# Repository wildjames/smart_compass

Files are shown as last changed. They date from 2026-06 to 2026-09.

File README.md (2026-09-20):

# Smart Compass

The product is going to be something similar to the compass in the Pirates of the Caribbean.

It has a ring of LEDs that indicate the direction you need to walk in to get to the place you want to be, which can be other devices in a tracking group, waypoints on a navigation route (e.g. hiking), Atlas Obscura sites for the city you're in, or some location you pinned (e.g. where you parked your car, or something like that).
Locations will be either pins dropped by the compass itself, or loaded to the device using a companion app on a phone - communicating with that means the device needs BLE. The nRF52840 module gives that.

The compass has a GNSS module for getting its own location, and a 9-axis IMU for the compass orientation.
It has a LoRa radio for kilometer-range mesh networking, allowing it to maintain an off-grid communication layer in cases where the cell network is either unavailable (e.g. rural locations, mountains), or overloaded (e.g. music festivals and other large events) - or if you just don't want to be carrying a phone (e.g. a kid being set loose in a shopping centre).

For typical single-device operation, however, the compass will rely on a companion phone app. Using the app, the user can navigate to desired location without referring to their phone. These can be user-defined, like setting the navigation destination on Maps, or get a list of Locations of Interest (LoI) from something like Atlas Obscura. I could also do a "hot/cold" thing with phone RSSI signal strength to get a kind of phone finder feature, but that may not be very useful.

## Design requirements

The device has a few core requirements:

- It must operate with no companion phone or PC. It's fine to have a phone for initial setup, or for additional features, but peer-to-peer operation must be entirely on-device.
- Tracking must be done by the device. The GNSS network must be used for this.
- The device must be secure - there must be no way for non-paired devices to be able to discern the location of a device, even if they are part of the same mesh network.
- Communication between devices must be long-range. Kilometer ranges between peers is a requirement, and longer ranges with a mesh network is also necessary.
- The battery must last for at least a day, but 3 day battery life is the target. Deep sleep, low power, and high polling modes should be used to assist this.
- The device must be handheld. No external antenna is ideal, but the option to add one may be worthwhile.
- The device must have flash storage
- The device needs an on-board way to communicate the direction and distance of paired devices.
  - The device must have a ring of addressable RGB LEDs for peer indication.
  - The device must have a haptic engine for feedback
  - The device may have a speaker for feedback.

I'm writing down user flows as I think of them in the [User Flow Library](UserFlowLibrary.md) page.

-----

## Archived KiCAD packages

- 0.1: First edition.
- 0.2: Submitted to reddit for hope of review. First hierarchical schematic.
- 0.3: Reviewed connections, fixed a few bugs with USB and SPI.
- 0.4: Rerouted the board to place the e-ink connector correctly, and the MCU more centrally. Also made the antenna placement more seriously, with proper clearance zone and via stitching.

-----

## Thoughts

The component cost per device is up to ~£50. The boards are about £5 per board for the first run (some heavy discounts, I shouldn't squander that). Assembled, the first shipment of 5 boards would cost $115 plus ~$60 in components per board makes that up to $400. That's a hefty chunk of cash. I could try getting just two assembled for this initial run, which brings it down to like, $200, but that's still pricey.

## TODO list

- Breaking the LED ring and display out to daughter boards is in progress. The two new schematics exist at [boards/led_ring/](boards/led_ring/) and [boards/display/](boards/display/); see [boards/README.md](boards/README.md) for the interconnect pinouts and what still has to be stripped out of the main board.
  - Similarly, it may be worth breaking the LoRa and GNSS out to a daughter board, which may make the antenna placement easier. Less compelling though, and probably not worth the extra thickness.
- I can apparently use a pi pico 2 as an SWD programmer, to flash the bootloader, and from there I can just upload via the native USB. I need to prove this out though.
- I will do the programming in Rust, using the Embassy ecosystem. This will give me the memory safety and speed of rust (nice when there is no easy way to see crashes on the device), but also the fearless concurrency will be a massive boon with all the ICs that need to be interfaced with.

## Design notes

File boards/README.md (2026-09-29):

# Board set

The Smart Compass is built as three PCBs. KiCad has no multi-board project, so
each one is its own project directory here, and the parts they share live in
`../libs/`.

| Directory | Project | What it is |
| --- | --- | --- |
| `main/` | `SmartCompass` | The engine board: MCU, GNSS, LoRa, IMU, flash, power tree, haptics, buttons, USB |
| `led_ring/` | `LedRing` | The 16-LED addressable RGB ring |
| `display/` | `Display` | The e-ink panel connector and its charge-pump support |

The ring and display were split off so the housing can be assembled and
modified without the main board's position dictating where they sit.

Parts that are not on any board - the haptic actuator, the panel, the cell, the
case switches and buttons, the antennas, and the cables and housings joining
them - are listed in [EXTRA_PARTS_BOM.md](EXTRA_PARTS_BOM.md), because they never
appear in a BOM exported from a schematic. Outstanding sourcing work and open
risks are in [COMPONENT_SOURCING.md](COMPONENT_SOURCING.md).

The main board's power tree can be simulated in KiCad's built-in SPICE
simulator; [main/sim/README.md](main/sim/README.md) explains the setup, what is
modelled and excluded, and the results so far. The part models are in
`../libs/spice/`.

## Libraries

`../libs/smart_compass.kicad_sym` and `../libs/smart_compass.pretty` hold the
parts the boards share. They were extracted from the main board, where they had
only ever existed embedded inside the `.kicad_sch` and `.kicad_pcb` files - they
were never in any library table, so a new project could not place them.

Footprints live alongside in `../libs/smart_compass.pretty/`, and 3D models in
`../libs/smart_compass.3dshapes/`.

3D models are referenced from inside the footprint with a
`${KIPRJMOD}/../../libs/smart_compass.3dshapes/...` path
The main board still resolves its other custom parts from its embedded copies,
which is why its ERC reports a long list of "configuration does not include
the symbol library" warnings. Those predate the split. Extracting the rest
into `libs/` would clear them.

Each daughter board has a project-scope `sym-lib-table` and `fp-lib-table`
pointing at `${KIPRJMOD}/../../libs/`, so the paths survive the repo being
cloned somewhere else.

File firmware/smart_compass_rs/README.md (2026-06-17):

# Smart compass firmware

There are a lot of things that need to be interfaced with. I'm going to go with Rust here, for the concurrency benefits and the seemingly mature ecosystem, though I'll have to evaluate that as I go...

## List of core dependencies

| Crate | Responsibility | Docs |
|---|---|---|
| `cortex-m` | Low-level access to Cortex-M peripherals (NVIC, SCB), critical section implementation for single-core nRF52840 | [docs.rs/cortex-m](https://docs.rs/cortex-m/0.7.7/cortex_m/) |
| `cortex-m-rt` | Startup runtime - defines the reset vector, memory layout, and `#[entry]` macro | [docs.rs/cortex-m-rt](https://docs.rs/cortex-m-rt/0.7.5/cortex_m_rt/) |
| `defmt` | Lightweight, deferred formatting logging framework for embedded (sends minimal data over RTT) | [docs.rs/defmt](https://docs.rs/defmt/1.1.0/defmt/) |
| `defmt-rtt` | Transport layer that streams `defmt` log frames over RTT (via SWD probe) | [docs.rs/defmt-rtt](https://docs.rs/defmt-rtt/1.2.0/defmt_rtt/) |
| `embassy-executor` | Async task executor for Cortex-M - runs Embassy tasks cooperatively | [docs.rs/embassy-executor](https://docs.rs/embassy-executor/0.10.0/embassy_executor/) |
| `embassy-nrf` | Hardware Abstraction Layer for nRF52840 - provides async drivers for GPIO, I2C, SPI, UART, PWM, etc. | [docs.rs/embassy-nrf](https://docs.rs/embassy-nrf/0.10.0/embassy_nrf/) |
| `embassy-time` | Async timers, delays, and time-keeping backed by the RTC peripheral | [docs.rs/embassy-time](https://docs.rs/embassy-time/0.5.1/embassy_time/) |
| `embedded-hal` | Standard hardware abstraction traits (I2C, SPI, GPIO) for portable device drivers | [docs.rs/embedded-hal](https://docs.rs/embedded-hal/1.0.0/embedded_hal/) |
| `nrf-sdc` | Rust bindings to Nordic's SoftDevice Controller - provides the BLE link layer | [docs.rs/nrf-sdc](https://docs.rs/nrf-sdc/0.3.0/nrf_sdc/) |
| `trouble-host` | BLE host stack (GATT, GAP) that runs on top of `nrf-sdc` - handles connections, services, characteristics | [docs.rs/trouble-host](https://docs.rs/trouble-host/0.6.0/trouble_host/) |

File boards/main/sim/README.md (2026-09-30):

# SPICE simulation of the main board

The main board schematic is set up for KiCad's built-in simulator (ngspice).
It simulates the power tree: USB input, charger, load-sharing power path,
3.3 V regulator, and the LED ring and haptics, which hang off the power path
output.
Everything else on the board appears as the current it draws.

## Running it

1. Open `SmartCompass.kicad_pro` and the schematic, then **Inspect → Simulator**.
2. Run the simulation. If KiCad asks for an analysis, choose a transient with
   a 10 µs step and a 3 s stop time. That is the `.tran` directive on the root
   sheet.
3. Add signals to the plot. The useful ones are `VBUS`, `/Power and USB/VSYS`,
   `+BATT`, `+3.3V` and `Vdrive`.

A run takes about 15 seconds.

The scenario is the block of `.param` directives on the root sheet, next to
the flash. Edit those values to change it: cell voltage (`VBAT`), cable
(`RCABLE`, `LCABLE`, `VUSB`), and the time of each event.

| Time | Event |
| ---- | ----- |
| 0 | On battery, idle: MCU running, GNSS acquiring, LoRa receiving, IMU on |
| 0.10 s | LoRa transmits at +22 dBm for 100 ms |
| 0.15 s | LED ring on (0.45 W average, the schematic's "typical") until 2.5 s |
| 0.25 s | Haptic buzz, 100 ms |
| 0.40 s | USB cable plugged in |
| 0.55 s | LoRa transmits again, now on USB |
| 0.70 s | e-ink refresh, 1 s |
| 1.00 s | USB cable pulled out |
| 1.02 s | LoRa transmits while the power path switches back to the cell |

## How it is put together

- **Part models:** [`libs/spice/smart_compass.spice`](../../../libs/spice/smart_compass.spice).
  These cover the charger (MCP73831-2), the 3.3 V LDO (RT9080-33), the
  load-sharing P-FET (DMP2045U), the VBUS Schottky (SS1040-AU), the charge LED
  (LTST-C191KRKT) and the LED-ring ferrite bead (MPZ1608S601A). Each one is
  fitted to its datasheet in `datasheets/`, and the file says which figures.
  The two ICs are behavioural. Their comments list what is modelled and what
  is not.
- **Fixtures:** [`fixtures.spice`](fixtures.spice). These stand in for what
  plugs into the board:
  - a Li-Po cell behind 0.15 Ω on the battery connector;
  - a USB host on the far end of a cable (resistance plus inductance) on the
    USB-C connector;
  - the LED-ring and e-ink boards on their flat-cable connectors.

  The digital and RF modules are modelled as the current they draw.
- **Passives:** resistors and capacitors need no model. KiCad simulates them
  from their values.
- Everything is attached through each symbol's `Sim.*` fields. You can see
  and edit these under Properties → Simulation Model. Load currents are
  subcircuit parameters, so one symbol can be overridden there.

### Load currents

| Load | Draw | Source |
| ---- | ---- | --- |
| nRF52840 module | 6 mA on 3.3 V, 1 µA on its VBUS pin | Estimate. The VBUS figure is kept small so VBUS decays slowly after unplugging, which is the pessimistic case |
| LoRa module | 7.6 mA receiving, 125 mA transmitting | Datasheet |
| GNSS module | 14 mA | Datasheet, acquisition at 3 V |
| IMU | 5 mA | Estimate |
| QSPI flash | 20 µA | Estimate, standby |
| Fuel gauge | 23 µA | Datasheet, active mode |
| Haptic driver + LRA | 60 mA while buzzing | Estimate |
| e-ink board | 8 mA while refreshing | Estimate |
| LED ring board | Power from `Vdrive` behind 32 µF, pulsed at the LEDs' 1 kHz PWM between 0.05 W (dark) and 1.4 W (full white), with the duty set by the average | Derived from the LED datasheet: 0.45 W typical, about 1.4 W with every LED full white |

The LEDs dim by switching each colour fully on or off at 1 kHz, so the ring's
draw is a train of full-power pulses rather than a steady current. The
fixture assumes every LED switches at the same moment. That is the worst
case: in practice each LED has its own oscillator, so they drift in and out
of step.

### Parts excluded from simulation

Every symbol must either have a model or be excluded. ngspice refuses a
circuit in which any node has no DC path to ground. The digital modules are
current sinks between their supply pins, so their signal pins are
unconnected in the simulation. Anything wired only to those pins would
float.

| Excluded | Why |
| --- | --- |
| Both 32.768 kHz crystals and their four 10 pF load capacitors | The oscillators are inside the MCU and IMU, which are only loads here. The capacitors would hang on nodes with no DC path. |
| The two 27 Ω USB data resistors, the 500 Ω NeoPixel data resistor, the 1 kΩ GNSS UART resistor | Each connects two pins that have no model, so both ends float. Signal integrity is not what this simulation looks at. |
| The GNSS antenna, its u.FL connector, the antenna ESD diode, the 0 Ω antenna link and the not-fitted matching parts | RF parts with no meaning at these frequencies. A value of "NM" cannot be simulated at all. |
| The IMU's 0.1 µF CAP capacitor and the haptic driver's 1 µF REG capacitor | Each decouples an internal regulator of an IC modelled only as a load, so it would sit on a floating node. |
| The power-switch pads | Excluding them leaves the switch open, which is the device switched on (the LDO enable is pulled up). |
| The SWD header, reset button, button pads, haptic LRA pads and the NeoPixel-return test point | Connect only to signal pins or to parts already modelled elsewhere. Excluding the buttons leaves them released. |

When you add a symbol to the main board, give it a `Sim.*` model or tick
**Exclude from simulation**. Otherwise the simulator stops with a "no
simulation model" or "singular matrix" error.

## Not simulated

- Thermal regulation in the charger.
- The LDO's current limit and over-temperature shutdown.
- The LDO's power supply rejection. Ripple on `VSYS` only reaches the 3.3 V
  rail in the simulation when the LDO is in dropout.
- The MLCCs' loss of capacitance with DC bias.
- PCB trace resistance and inductance.
- Anything on the LED ring or display boards beyond their input capacitance
  and load.

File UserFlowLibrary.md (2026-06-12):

# User Flows

This is a project where the product will have a fair few things to do with it. Enough that, in order to help me be confident I've thought it through, it's worth making a library of what I want to have in the end.

I'm gonna split this into two parts - first, from the users' perspective, and then from the technical perspective.

For IO, the compass will have 3 user buttons, which will generally fill the role of up, down, and select. There is the e-ink screen for low-cadence information, and the LED ring for high-cadence information. There is also a haptic engine for vibrations, which I won't define here and instead just go by feel later on.

## User perspective

As far as the user is concerned, the device has:
- a name
- a list of devices it is tracking

and a few modes:
- Tracking mode (where the LEDs light up to show the intended direction of travel)
  - Devices/phones
  - Navigation waypoints
  - LoI
- Silent mode (where the device stops reporting its location, but can still track other devices)
- Low-frequency polling mode
- high frequency polling mode

### Phone pairing

- I turn on the device
- I open the bluetooth menu on my phone
- I navigate to the "Set up Compass" settings page in the device screen using the user buttons
- I see the device as "SmartCompass XYZ123" in the available devices menu and connect to it
- I open the app on my phone
- The app knows that a new device has been connected and needs pairing
- The app prompts me for a device name
- I enter it and submit
- After a few moments, I see a confirmation page telling me the device is ready to use

### On-device device pairing

- I have a device that is already set up
- I navigate to the "Add friend" page on the device screen on device A
- The other party navigates to the "Add friend" page on the device screen on device B
- I hold the two devices close to each other
- The devices each send a pairing request to each other, and the LEDs indicate a pairing request by flashing the same random colour and pattern
- I press the "select" button to accept, or the "up/down" buttons to reject
  - If either party rejects, then neither device saves the other
  - If the parties take longer than 60s to accept/reject, consider this a rejection
  - If the devices move out of range of each other within the timeout, consider this a rejection
- If/when connected to a companion phone, the device updates it with the current tracked device list

### In-app device pairing

- I have paired a phone to the device
- I open the app and navigate to the "add friend" page
- I search for that friend's username or email
- The other party recieves a request to track
- The other party accepts the request
- I can now track the other party

### Stop location broadcasting (silent mode)

- I have a device set up and paired with a phone
- I turn on the power switch for the device
- The device is broadcasting its location
- I simultaneously press the "up" and "down" user buttons together for 1s
- The device screen indicates that broadcasting has stopped
- The device LED ring indicates that broadcasting has stopped

### Start location broadcasting

- I have a device set up and paired with a phone
- I turn on the power switch for the device
- Location broadcasting is on by default, but the user has turned on silent mode
- The device is not currently broadcasting its location
- I simultaneously press the up and "down" user buttons together for 1s
- The device screen indicates that broadcasting has begun
- The device LED ring indicates that broadcasting has begun

### Start HTR broadcasting

- I have a device set up and paired with a phone
- The device is currently broadcasting a location
- I use the 3 user buttons to navigate the on-screen menu to the location broadcasting page
- I select the "Start HTR sharing" option

### Stop HTR broadcasting

- I have a device set up and paired with a phone
- The device is currently broadcasting a location
- I use the 3 user buttons to navigate the on-screen menu to the location broadcasting page
- I select the "Stop HTR sharing" option

### Set navigation route

- I have a device set up and paired with a phone
- The device is currently connected to the phone
- I open the app and navigate to the "Navigation" page
- I type in a destination to the search box
- The app returns results from Google Maps
- I select a target location
- The app indicates that navigation has started
- The app shows the route
- The device screen indicates that navigation has started, and displays key information about the route
- The device LED ring indicates that navigation has started, then points to the first waypoint along the route
- The screen updates key information on a 60s cadence
- The user is able to cancel navigation by either powering off the device (no resume on reboot), or double-tapping the "select" button
- When the user arrives at the waypoint, the LED ring indicates a waypoint was reached and begins tracking the next waypoint
- When the user arrives at the destination, the LED ring indicates arrival and the screen updates to do the same.

### Track LoI nearby

- I have a device set up and paired with a phone
- The device is currently connected to the phone, which is used to fetch data
- I use the 3 user buttons to navigate to "Track nearby LoI"
- The LED ring indicates the direction of the 3 nearest LoI
- The screen shows the name of the LoI that is currently closest to 0 degrees, and the distance to it
- When the user arrives at an LoI, the device LED ring indicates arrival
- The screen shows the LoI name
- When the user arrives at an LoI, the phone app sends a notification and opens the wikipedia page for it

### Start tracking a specific person

- I have a device set up
- I use the 3 user buttons to navigate to "Track person"
- I see a list of paired people, with untrackable people grayed out
  - "Untrackable" means no location data currently available for that person
  - I may add a "Patchy signal" mode, where the last known location can still be tracked?
- I use the user buttons to navigate to the person to track, and select them
- The LED ring indicates the direction of the person being tracked
- The device screen shows the name of the person being tracked

### Define a tracking group

- I have a device set up and paired with a phone
- The device is currently connected to the phone
- I open the app and navigate to the "Groups" page
- I select "Create new group"
- I enter a group name
- I select members from my list of paired devices/friends
- I confirm the group
- The app shows the new group in my groups list
- The device receives the updated group information

### Start tracking a group of people

- I have a device set up with at least one group defined
- I use the 3 user buttons to navigate to "Track group"
- I use the up/down buttons to scroll through available groups
- I press "select" to choose a group
- The LED ring indicates the direction of each group member with a different colour
- The device screen shows the group name and a list of members with distances

### Stop tracking

- I am currently tracking a person or group
- I long-press the "select" user button
- The LED ring stops indicating directions
- The device screen confirms that tracking has stopped and returns to the main menu

### Power on

TODO

### Power off

TODO

### Low battery indication

TODO

### Firmware update

TODO - Is OTA updating feasible? Perhaps that's the first feature to implement. Can I do it from the app? Directly from a PC?

### Remove a friend

TODO

### Edit a tracking group

TODO

### Delete a tracking group

#### On-device

- I have set up a tracking group previously
- I navigate to the device settings > "Delete tracked thing" menu on the device screen using the 3 user buttons
- I see a menu of "Groups", "Friends", "Locations"
- I select "Groups", and see a list of my tracking group names
- I select the group to delete, and see a "Are you sure?" screen, which contains the group name
- I select "yes" or "no".
- After selection, I return to the list of groups

#### In-app

- I have set up a tracking group previously
- I navigate to the "Manage Tracking Groups" page in the app
- I select the group to delete
- I select the "Delete" button
- I am presented with a confirmation page, and choose an option
- I am returned either to the selected group management page if I do not delete it, or the list of groups page if I did delete the group.

### Tracked person goes offline

TODO

### Tracked person enters silent mode

TODO - should this look the same as the person going offline, or should I communicate the silent mode to the tracker?

## Technical perspective

Each device contains the following information about itself:
- The device name (human-readable)
- The device UUID
- A sigining key pair (pub/priv pair)
- An encryption key pair (pub/priv pair)

Each device tracks the following information about other "partner" devices, for each partner:
- The partner name
- The partner UUID
- The partner public signing key
- The partner public encryption key

Devices have three modes of location broadcasting:
- No broadcasting
- Low time resolution location broadcasting (LTR) (default)
- High time resolution location broadcasting (HTR)

### Phone pairing

This is the initial setup for a user with a new device, or the resetting process for a device that is already set up.

1. The user signals that the device is entering pairing mode
1. The controller clears all previous pairing associations
1. The controller starts the bluetooth radio, if it is not already enabled
1. The controller starts advertising
1. The user pairs their phone to the device
1. The user opens a mobile app, and configures a device name
1. The mobile app sends a message to the device, updating its name
1. The device clears its list of tracked devices, and rotates its cryptographic keys
1. The device sends a message to the app indicating that the setup was successful and informs the app of the device's UUID and public key

### On-device device pairing

This is the process to take two physical devices that are nearby, and set it up so that one tracks the other (device-to-device pairing)

### In-app device pairing

This is the process to use the app to search for another device that is not nearby, and request that partner's information from the remote server (app-to-app pairing)

### Device location broadcasting (LTR)
### Device location broadcasting (HTR)
### Device group tracking
### Device individual tracking

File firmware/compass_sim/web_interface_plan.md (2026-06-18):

# Compass Simulator Web Interface Plan

## Goal

Add a lightweight web UI that allows direct control of mocked ICs while the compass simulator runs indefinitely.

## Architecture

```
┌─────────────┐       ┌──────────────────┐       ┌─────────────┐
│  Browser UI │◄─────►│ Axum HTTP Server │◄─────►│SimController│
│  (HTML/JS)  │  REST │ (localhost:3000) │  Arc  │Arc<Mutex<…>>│
└─────────────┘       └──────────────────┘       └──────┬──────┘
                                                        │
                                                        ▼
                                                 ┌──────────────┐
                                                 │ MockI2cBus   │
                                                 │  ┌─────────┐ │
                                                 │  │FuelGauge│ │
                                                 │  └─────────┘ │
                                                 │  (future ICs)│
                                                 └──────┬───────┘
                                                        │
                                                        ▼
                                                 ┌─────────────┐
                                                 │   Compass   │
                                                 │  (polling)  │
                                                 └─────────────┘
```

The existing `SimController` already uses `Arc<Mutex<...>>` for device state, making it trivially sharable between the compass polling loop and HTTP handlers.

## Dependencies to Add

```toml
axum = "0.8"
serde = { version = "1", features = ["derive"] }
serde_json = "1"
tower-http = { version = "0.6", features = ["cors"] }
```

## REST API Endpoints

| Method | Path | Body | Description |
|---|---|---|---|
| `GET` | `/api/state` | — | Returns full simulator state (voltage, SOC, charge rate, last reading) |
| `POST` | `/api/battery` | `{ "voltage": 3.8, "soc": 62.5 }` | Set battery voltage and SOC |
| `POST` | `/api/charge_rate` | `{ "rate": -2.1 }` | Set charge/discharge rate (%/hr) |
| `POST` | `/api/error` | `{ "kind": "nack" \| "bus_error" }` | Inject a one-shot I2C error |
| `GET` | `/api/fuel_gauge` | — | Latest `Compass::read_fuel_gauge()` result |
| `GET` | `/` | — | Serve the HTML/JS UI |

## Frontend (Single-Page HTML)

A single `index.html` served as an embedded string or from a `static/` directory:

- **Status panel**: Displays current simulated state + last compass reading (auto-refreshes via polling or SSE)
- **Controls**:
  - Voltage slider (2.5V – 4.2V)
  - SOC slider (0% – 100%)
  - Charge rate input (-10 to +10 %/hr)
  - "Inject Error" buttons (NACK, Bus Error)
- **Log**: Scrolling list of compass readings over time

No build tooling — vanilla HTML + JS + fetch API.

## Changes to `main.rs`

Replace the scripted scenario with:

```rust
tokio::select! {
    _ = compass.start() => {},
    _ = web::serve(controller) => {},
}
```

Both tasks run concurrently:
- `compass.start()` polls the mock bus indefinitely
- `web::serve()` runs the axum server on `0.0.0.0:3000`

## File Structure

```
compass_sim/
├── Cargo.toml              (add deps)
├── src/
│   ├── main.rs             (simplified: create sim, start both tasks)
│   ├── lib.rs              (add `pub mod web;`)
│   ├── web/
│   │   ├── mod.rs          (router setup, serve function)
│   │   ├── handlers.rs     (endpoint handler functions)
│   │   └── state.rs        (shared AppState struct)
│   ├── mock/               (unchanged)
│   └── static/
│       └── index.html      (embedded or served from disk)
```

## Implementation Steps

1. Add dependencies to `Cargo.toml`
2. Create `src/web/state.rs` — `AppState` struct wrapping `Arc<SimController>`
3. Create `src/web/handlers.rs` — handler functions for each endpoint
4. Create `src/web/mod.rs` — router construction and `serve()` async fn
5. Create `src/static/index.html` — single-page UI
6. Update `src/lib.rs` to export `pub mod web`
7. Rewrite `src/main.rs` to run indefinitely with both tasks
8. Test: `cargo run`, open `http://localhost:3000`

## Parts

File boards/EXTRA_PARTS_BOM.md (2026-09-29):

# Extra parts BOM

Everything the finished compass needs that is **not** on a board, and so never
appears in a BOM exported from a schematic.

Quantities are per finished unit unless stated. Stock and lead figures were read
from Digi-Key and will drift; re-check before ordering.

## Ready to order

| Part | What it is | Qty | Digi-Key | Notes |
| ---- | --- | --- | --- | ----- |
| Vybronics `VLV101040A` | Haptic actuator, 10 x 10 x 4 mm linear resonant | 1 | `1670-VLV101040A-ND` | [Datasheet](../datasheets/VLV101040A_Vybronics.pdf) |
| 28 AWG stranded hook-up wire, silicone insulated | All five case leads, soldered straight to the board | ~1 m | - | Silicone rather than PVC: the case halves stay tethered once the connectors are gone, so this wire gets flexed every time the unit is opened. Insulation OD should be about 1 mm to suit the pad footprints |
| 32 or 34 AWG UL3302 | The short stub from the actuator pads to the splice | ~100 mm | - | Vybronics only permits this gauge against the actuator's pressure pads |
| Waveshare 1.54inch e-Paper V2 | 200 x 200 panel, SSD1681 driver | 1 | - | The display board is built against this exact module — see [`../datasheets/1.54inch_e-paper_V2_Datasheet.pdf`](../datasheets/1.54inch_e-paper_V2_Datasheet.pdf) |
| Taoglas `FXP890.07.0100C` | LoRa antenna: 863–928 MHz flexible polyimide PCB antenna, 62.2 x 20 mm, 100 mm 1.13 mm coax ending in an I-PEX MHF1 (U.FL) plug | 1 | `931-FXP890.07.0100C-ND` | Plugs straight into the radio module's own onboard IPEX connector. [Datasheet](../datasheets/FXP890.07.0100C_Taoglas.pdf), and see the placement note below |

## Decided, but not yet sourced

| Part | What it is | Qty | Notes |
| ---- | --- | --- | ----- |
| 10-way 0.5 mm FFC cable | Board-to-board, ring link and display link | 2 | Both links use the same connector at both ends, so one cable part serves both. **Length and contact side still to be decided** — see the warning below |
| LiPo cell, 504050 or 505050 | ~1000 mAh, fits behind the PCB | 1 | Almost always ships with a JST PH 2-pin plug already fitted, which mates the board's battery header directly — no crimping needed |
| Power switch | Case-mounted, SMD or through-hole | 1 | Pulls the load switch's enable node down against a 1M pull-up, so the lead carries microamps and current rating is not a constraint here. |
| User Buttons | Case-mounted, SMD or through-holE | 3 | These will be the primary point of contact for the user, so make sure these are good! |

## Notes

**The LoRa antenna sits in the rim.**
Wrapped around the inside of the case, it is bent to a 40 mm radius, which
the polyimide takes easily but which does pull the tuning slightly off the
flat, free-space figures in the datasheet. It may be worth trying to get it
to sit against the face, if possible, to eliminate the bend if this turns out
to be an issue.

Keep it away from the GNSS antenna and lipo as much as possible - nearby metal
interferes with the tuning and will reduce efficiency.

This is an IPEX plug, so we can always move to an external antenna later, if we
need to.

**The FFC cables are not symmetrical.** Both board-to-board links use the same
10-way 0.5 mm connector at both ends, so one cable part number covers both — but
neither pinout is a palindrome, and a cable fitted the wrong way round puts the
LED ring's supply onto ground pins. The ring link also carries the ring's enable
signal on a conductor that used to be a spare supply, which makes getting it
right more consequential than it once was. Both pinouts are in
[`README.md`](README.md), and the conductor order belongs on the assembly
drawing.

**The haptic actuator's contacts are not solder tabs.** It ships with pressure
contacts intended for pogo pins or spring fingers against a PCB. Vybronics
explicitly permits thin flexible flying leads instead — UL3302, AWG 32 or 34 —
which is what the pigtail should use at the actuator end. Do not assume ordinary
hook-up wire will do; it is too stiff for the contact pads and will load the
moving mass.

**The pigtail still needs a splice.** 32/34 AWG is too fine to be the whole run.
It would be fragile against the board pads and is far below the 1 mm insulation
the pad footprint is drawn for. So the thin wire stays a short stub at the
actuator and is spliced to a 28 AWG run, and that run is what solders into the
board. Two things follow,

- **Keep the splice short and put it at the actuator end**, within roughly
  10 mm of the contact pads, so the great majority of the flying lead is the
  stiffer 28 AWG and only a stub of 32/34 AWG is unsupported.
- **Bond the splice down.** It is the weakest joint in the whole assembly — a
  hand-soldered butt joint in a flying lead, on the one lead attached to a
  vibrating mass, inside a device that gets carried in a pocket. Adhesive at
  the splice keeps the vibration out of the joint and stops the moving mass
  being loaded by the heavier wire.

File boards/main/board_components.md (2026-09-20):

# Medallion Board

## External components

All three buttons share one lead, soldered straight into the board. Four plated through-holes with a feed-through strain relief, one per button signal plus a fourth for the ground return they have in common. So the case buttons are built and fitted as one harness rather than three. Use 28 AWG stranded with silicone insulation - the halves stay tethered, so this wire gets flexed every time the unit is opened. I've not settled on buttons yet. There are two options - either side-mounted tactile smd buttons like [these](https://www.amazon.co.uk/ECSiNG-Momentary-5x7-8x3-5mm-Controls-Dashboards/dp/B0GFPX8CMW/ref=sr_1_3?sr=8-3), or through hole button like [this](https://www.amazon.co.uk/10PCS-Momentary-Push-Button-Switch/dp/B0FHVRM49T/ref=sr_1_3?sr=8-3).

There will also be a power switch on the case - it can interface with [this](https://www.amazon.co.uk/sourcingmap%C2%AE-Position-Locking-Switch-7x2x1mm/dp/B01N25FBWD) SMD switch, or possibly the [chunkier cousin](https://www.amazon.co.uk/Miniature-Model-Railway-Switch-2-Position/dp/B00TXNXFZC/) that has through-hole legs.

I should be able to fit a 504050 or 505050 LiPo behind the PCB. That gives approx 1000mAh capacity, e.g. [here](https://www.ebay.co.uk/itm/375695071227) and [here](https://www.ebay.co.uk/itm/195457885965)

For the haptic engine, use the Vybronics `VLV101040A` - a 10 x 10 x 4 mm linear resonant actuator giving 2.75 G at 170 Hz with a 10 ms rise time ([datasheet](../../datasheets/VLV101040A_Vybronics.pdf), and it is on the [extra parts BOM](../EXTRA_PARTS_BOM.md)). It needs to be adhered to the rear of the case to work properly. Note that its contacts are pressure pads meant for pogo pins, not solder tabs - Vybronics permits thin UL3302 AWG 32/34 flying leads instead, which is what the pigtail should be made from.

For the LoRa antenna, I plan on using a PCB antenna, e.g. [here](https://www.amazon.co.uk/915MHz-Antenna-Meshtastic-Development-Boards-Black/dp/B0FLVF19CQ). I think these are flexible PCB antennas, so can bend to fit the contour of the case. This should not affect the performance too much.

## System Block Diagrams

### Power

```mermaid
flowchart LR
    USBC[USB-C X1] -->|VBUS| CHARGER[MCP73831]
    CHARGER --> VBAT[VBAT Rail]
    VBAT --> SUPERCAP[C8 100mF]
    VBAT --> LDO[RT9080-33GJ5]
    VBAT --> VLED[VLED Rail]
    LDO --> VDD[3.3V Rail]

    MCU[nRF52840] <-->|I²C| FUEL[MAX17048 Fuel Gauge]
    FUEL -->|GPIO: LOW_BATT| MCU
    USBC -->|USB D+/D-| MCU
```

### Navigation & Positioning

```mermaid
flowchart LR
    MCU[nRF52840] <-->|UART| GNSS[LC86LICMD GNSS]
    MCU -->|GPIO: GNSS_RESET| GNSS

    MCU <-->|I²C| IMU[BNO086 IMU]
    MCU -->|GPIO: BNO_NINT BNO_NRST| IMU
```

### Communication

```mermaid
flowchart LR
    MCU[nRF52840] <-->|SPI| LORA[LoRa Wio-E5]
    MCU -->|GPIO: LORA_NSS LORA_NRST| LORA
    LORA -->|GPIO: LORA_DIO LORA_BUSY LORA_RF_SW| MCU
```

### Storage

```mermaid
flowchart LR
    MCU[nRF52840] <-->|SPI| FLASH[Flash Memory]
    MCU -->|GPIO: FLASH_CS RST WP| FLASH
```

### Display & Feedback

```mermaid
flowchart LR
    MCU[nRF52840] -->|SPI| J7[J7 FFC]
    MCU -->|GPIO: DISP_CS DC RES BUSY| J7
    J7 --> EINK[Display board]

    MCU -->|1-Wire: NEOPIX| R13[R13 500R]
    R13 --> J6[J6 FFC]
    J6 --> LEDS[LedRing board]
    J6 -->|NEOPIX_RET| TP1[TP1 test pad]

    MCU <-->|I²C| HAPTIC[Haptic Engine]
    MCU -->|GPIO: DRV_EN| HAPTIC
```

### User Input & Debug

```mermaid
flowchart LR
    MCU[nRF52840] -->|GPIO: JST1| BTN1[P3 JST BTN 1]
    MCU -->|GPIO: JST2| BTN2[P5 JST BTN 2]
    MCU -->|GPIO: JST3| BTN3[P4 JST BTN 3]
    MCU --- SW[Reset Button]

    MCU -->|SWD| SWD[SWD Header]
    MCU --> HEADER[GPIO / I²C Breakout]
```

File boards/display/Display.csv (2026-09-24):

Reference | Qty | Value | DNP | Exclude from BOM | Exclude from Board | Footprint | Datasheet | DigiKey_PN | MPN
C1,C3,C4,C5,C7,C8,C10,C11 | 8 | 1uF |  |  |  | Capacitor_SMD:C_0603_1608Metric | https://product.tdk.com/system/files/dam/doc/product/capacitor/ceramic/mlcc/catalog/mlcc_commercial_general_en.pdf | 445-C1608X7R1H105K080ABCT-ND | C1608X7R1H105K080AB
C2 | 1 | 10uF |  |  |  | Capacitor_SMD:C_0805_2012Metric | https://product.tdk.com/system/files/dam/doc/product/capacitor/ceramic/mlcc/catalog/mlcc_automotive_general_en.pdf | 445-6970-1-ND | CGA4J3X5R1A106K125AB
C6,C9 | 2 | 4.7uF |  |  |  | Capacitor_SMD:C_1206_3216Metric | https://mm.digikey.com/Volume0/opasdata/d220001/medias/docus/658/CL31B475KBHNFNE_Spec.pdf | 1276-3179-1-ND | CL31B475KBHNFNE
D1,D2,D3 | 3 | MBR0540 |  |  |  | Diode_SMD:D_SOD-123 | https://www.mccsemi.com/pdf/Products/MBR0520-MBR0580(SOD123).pdf | MBR0540TPMSCT-ND | MBR0540-TP
J1 | 1 | FH12-10S-0.5SH(55) |  |  |  | Connector_FFC-FPC:Hirose_FH12-10S-0.5SH_1x10-1MP_P0.50mm_Horizontal | https://www.hirose.com/product/document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 | HFJ110CT-ND | FH12-10S-0.5SH(55)
J2 | 1 | FH12-24S-0.5SH(55) |  |  |  | smart_compass:HRS_FH12-24S-0.5SH_55_ | https://www.hirose.com/product/document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 | HFJ124CT-ND | FH12-24S-0.5SH(55)
L1 | 1 | 10uH |  |  |  | smart_compass:L_Bourns_SRN3015BTA | https://www.bourns.com/docs/Product-Datasheets/SRN3015BTA.pdf | 118-SRN3015BTA-100MCT-ND | SRN3015BTA-100M
Q1 | 1 | IRLML6346 |  |  |  | Package_TO_SOT_SMD:SOT-23 | https://www.infineon.com/assets/row/public/documents/24/49/infineon-irlml6346-datasheet-en.pdf | IRLML6346TRPBFCT-ND | IRLML6346TRPBF
R1 | 1 | 10K |  |  |  | Resistor_SMD:R_0603_1608Metric | https://yageogroup.com/content/datasheet/asset/file/PYU-RC_GROUP_51_ROHS_L | 311-10.0KHRCT-ND | RC0603FR-0710KL
R2 | 1 | 3R |  |  |  | Resistor_SMD:R_0603_1608Metric | https://yageogroup.com/content/datasheet/asset/file/PYU-RC_GROUP_51_ROHS_L | 13-RC0603FR-073RLCT-ND | RC0603FR-073RL

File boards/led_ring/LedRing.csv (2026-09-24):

Reference | Qty | Value | DNP | Exclude from BOM | Exclude from Board | Footprint | Datasheet | DigiKey_PN | MPN
C1,C3,C4 | 3 | 22uF |  |  |  | Capacitor_SMD:C_0805_2012Metric | https://media.digikey.com/pdf/Data%20Sheets/Samsung%20PDFs/CL21A226KPCLRNC_Spec.pdf | 1276-6786-1-ND | CL21A226KPCLRNC
C2 | 1 | 10uF |  |  |  | Capacitor_SMD:C_0805_2012Metric | https://product.tdk.com/system/files/dam/doc/product/capacitor/ceramic/mlcc/catalog/mlcc_automotive_general_en.pdf | 445-6970-1-ND | CGA4J3X5R1A106K125AB
C5,C6,C7,C8,C9,C10,C11,C12,C13,C14,C15,C16,C17,C18,C19,C20,C21 | 17 | 0.1uF |  |  |  | Capacitor_SMD:C_0402_1005Metric | https://media.digikey.com/pdf/Data%20Sheets/Samsung%20PDFs/CL05B104KO5VPNC_Spec.pdf | 1276-6844-1-ND | CL05B104KO5VPNC
D1,D2,D3,D4,D5,D6,D7,D8,D9,D10,D11,D12,D13,D14,D15,D16 | 16 | IN-PI15TAT5R5G5B |  |  |  | smart_compass:LED_Inolux_IN-PI15TAT5R5G5B_1515 | https://www.inolux-corp.com/details.php?i=286 | 1830-IN-PI15TAT5R5G5BCT-ND | IN-PI15TAT5R5G5B
J1 | 1 | FH12-10S-0.5SH(55) |  |  |  | Connector_FFC-FPC:Hirose_FH12-10S-0.5SH_1x10-1MP_P0.50mm_Horizontal | https://www.hirose.com/product/document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 | HFJ110CT-ND | FH12-10S-0.5SH(55)
L1 | 1 | 2.2uH |  |  |  | Inductor_SMD:L_1008_2520Metric | https://www.murata.com/products/productdetail?partno=DFE252010F-2R2M%3DP2 | 490-13042-1-ND | DFE252010F-2R2M=P2
R1 | 1 | 2.2K |  |  |  | Resistor_SMD:R_0603_1608Metric | https://yageogroup.com/content/datasheet/asset/file/PYU-RC_GROUP_51_ROHS_L | 311-2.20KHRCT-ND | RC0603FR-072K2L
R2 | 1 | 3.9K |  |  |  | Resistor_SMD:R_0603_1608Metric | https://yageogroup.com/content/datasheet/asset/file/PYU-RC_GROUP_51_ROHS_L | 311-3.90KHRCT-ND | RC0603FR-073K9L
R3 | 1 | 732K |  |  |  | Resistor_SMD:R_0603_1608Metric | https://yageogroup.com/content/datasheet/asset/file/PYU-RC_GROUP_51_ROHS_L | 311-732KHRCT-ND | RC0603FR-07732KL
R4 | 1 | 100K |  |  |  | Resistor_SMD:R_0603_1608Metric | https://yageogroup.com/content/datasheet/asset/file/PYU-RC_GROUP_51_ROHS_L | 311-100KHRCT-ND | RC0603FR-07100KL
U1 | 1 | TPS61023 |  |  |  | Package_TO_SOT_SMD:SOT-563 | https://www.ti.com/lit/ds/symlink/tps61023.pdf | 296-TPS61023DRLRCT-ND | TPS61023DRLR
U2 | 1 | 74AHCT1G125 |  |  |  | Package_TO_SOT_SMD:SOT-23-5 | https://www.ti.com/lit/ds/symlink/sn74ahct1g125.pdf | 296-4708-1-ND | SN74AHCT1G125DBVR

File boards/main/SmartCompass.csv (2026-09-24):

Reference | Qty | Value | DNP | Exclude from BOM | Exclude from Board | Footprint | Datasheet | MPN | DigiKey_PN
AE1 | 1 | 1575AT43A0040E |  |  |  | smart_compass:ANT_1575AT_JOT | https://www.johansontechnology.com/part/1575AT43A0040001E/pdf/ | 1575AT43A0040001E | 712-1575AT43A0040001ECT-ND
BATT1 | 1 | JST_PH |  |  |  | smart_compass:JST_S2B-PH-SM4-TB | https://www.jst-mfg.com/product/pdf/eng/ePH.pdf | S2B-PH-SM4-TB | 455-S2B-PH-SM4-TBCT-ND
C1,C2,C8,C9,C10,C12,C19,C22,C24 | 9 | 10uF |  |  |  | Capacitor_SMD:C_0805_2012Metric | https://product.tdk.com/system/files/dam/doc/product/capacitor/ceramic/mlcc/catalog/mlcc_automotive_general_en.pdf | CGA4J3X5R1A106K125AB | 445-6970-1-ND
C3,C4 | 2 | 12pF |  |  |  | Capacitor_SMD:C_0402_1005Metric | https://media.digikey.com/pdf/Data%20Sheets/Samsung%20PDFs/CL05C120JB5NNNC_Spec.pdf | CL05C120JB5NNNC | 1276-1178-1-ND
C5,C20,C21 | 3 | 1uF |  |  |  | Capacitor_SMD:C_0603_1608Metric | https://product.tdk.com/system/files/dam/doc/product/capacitor/ceramic/mlcc/catalog/mlcc_commercial_general_en.pdf | C1608X7R1H105K080AB | 445-C1608X7R1H105K080ABCT-ND
C6,C13,C15,C16,C17,C18,C23 | 7 | 0.1uF |  |  |  | Capacitor_SMD:C_0402_1005Metric | https://media.digikey.com/pdf/Data%20Sheets/Samsung%20PDFs/CL05B104KO5VPNC_Spec.pdf | CL05B104KO5VPNC | 1276-6844-1-ND
C7,C11 | 2 | 4.7uF |  |  |  | Capacitor_SMD:C_1206_3216Metric | https://mm.digikey.com/Volume0/opasdata/d220001/medias/docus/658/CL31B475KBHNFNE_Spec.pdf | CL31B475KBHNFNE | 1276-3179-1-ND
C14 | 1 | 22uF |  |  |  | Capacitor_SMD:C_0805_2012Metric | https://media.digikey.com/pdf/Data%20Sheets/Samsung%20PDFs/CL21A226KPCLRNC_Spec.pdf | CL21A226KPCLRNC | 1276-6786-1-ND
C25,C26 | 2 | NM | DNP |  |  | Capacitor_SMD:C_0402_1005Metric |  | DNP
CHG1 | 1 | RED |  |  |  | LED_SMD:LED_0603_1608Metric | https://optoelectronics.liteon.com/upload/download/DS22-2000-223/LTST-C191KRKT.PDF | LTST-C191KRKT | 160-1447-1-ND
D1 | 1 | MBR0540 |  |  |  | Diode_SMD:D_SOD-123 | https://www.mccsemi.com/pdf/Products/MBR0520-MBR0580(SOD123).pdf | MBR0540-TP | MBR0540TPMSCT-ND
D2 | 1 | TPD1E05U06DPYR |  |  |  | smart_compass:DIO_TPD1E05U06DPYR | https://www.ti.com/general/docs/suppproductinfo.tsp?distId=10 | TPD1E05U06DPYR | 296-39341-1-ND
FB1 | 1 | 600R@100MHz |  |  |  | Inductor_SMD:L_0603_1608Metric | https://product.tdk.com/en/system/files | MPZ1608S601ATA00 | 445-MPZ1608S601ATA00CT-ND
HAPTIC1 | 1 | HAPTIC_PADS |  |  |  | Connector_Wire:SolderWire-0.127sqmm_1x02_P3.7mm_D0.48mm_OD1mm_Relief
IC1 | 1 | Wio-SX1262 |  |  |  | smart_compass:MODULE12P-1.27-11X11.6MM | https://files.seeedstudio.com/products/SenseCAP/Wio_SX1262/Wio-SX1262_Module_Datasheet.pdf | 114993390 | 1597-114993390CT-ND
J3,J4 | 2 | FH12-10S-0.5SH(55) |  |  |  | Connector_FFC-FPC:Hirose_FH12-10S-0.5SH_1x10-1MP_P0.50mm_Horizontal | https://www.hirose.com/product/document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 | FH12-10S-0.5SH(55) | HFJ110CT-ND
J5 | 1 | IPEX |  |  |  | smart_compass:SMT_9.001E.01_TAL | https://cdn.taoglas.com/datasheets/RECE.20369.001E.01.pdf | RECE.20369.001E.01 | 931-1157-1-ND
ONOFF1 | 1 | PWRSW_PADS |  |  |  | Connector_Wire:SolderWire-0.127sqmm_1x02_P3.7mm_D0.48mm_OD1mm_Relief
Q1 | 1 | DMP2045U |  |  |  | Package_TO_SOT_SMD:SOT-23 | https://www.diodes.com/assets/Datasheets/DMP2045U.pdf | DMP2045U-7 | DMP2045U-7DICT-ND
R1,R2,R4,R10 | 4 | 5.1K |  |  |  | Resistor_SMD:R_0603_1608Metric | https://industrial.panasonic.com/cdbs/www-data/pdf/RDA0000/AOA0000C304.pdf | ERJ-3EKF5101V | P5.10KHCT-ND
R3,R5 | 2 | 27R |  |  |  | Resistor_SMD:R_0603_1608Metric | https://yageogroup.com/content/datasheet/asset/file/PYU-RC_GROUP_51_ROHS_L | RC0603FR-0727RL | 311-27.0HRCT-ND
R6,R7 | 2 | 4.7K |  |  |  | Resistor_SMD:R_0603_1608Metric | https://yageogroup.com/content/datasheet/asset/file/PYU-RC_GROUP_51_ROHS_L | RC0603FR-074K7L | 311-4.70KHRCT-ND
R8,R14,R15,R16,R17 | 5 | 10K |  |  |  | Resistor_SMD:R_0603_1608Metric | https://yageogroup.com/content/datasheet/asset/file/PYU-RC_GROUP_51_ROHS_L | RC0603FR-0710KL | 311-10.0KHRCT-ND
R9,R12,R19 | 3 | 100K |  |  |  | Resistor_SMD:R_0603_1608Metric | https://yageogroup.com/content/datasheet/asset/file/PYU-RC_GROUP_51_ROHS_L | RC0603FR-07100KL | 311-100KHRCT-ND
R11 | 1 | 3.9K |  |  |  | Resistor_SMD:R_0603_1608Metric | https://yageogroup.com/content/datasheet/asset/file/PYU-RC_GROUP_51_ROHS_L | RC0603FR-073K9L | 311-3.90KHRCT-ND
R13 | 1 | 500R |  |  |  | Resistor_SMD:R_0603_1608Metric | https://yageogroup.com/content/datasheet/asset/file/PYU-RT_1-TO-0-01_ROHS_L | RT0603BRC07500RL | 13-RT0603BRC07500RLCT-ND
R18 | 1 | NM | DNP |  |  | Resistor_SMD:R_0603_1608Metric |  | DNP
R20,R21 | 2 | 1K |  |  |  | Resistor_SMD:R_0603_1608Metric | https://yageogroup.com/content/datasheet/asset/file/PYU-RC_GROUP_51_ROHS_L | RC0603FR-071KL | 311-1.00KHRCT-ND
R22 | 1 | 0R |  |  |  | Resistor_SMD:R_0603_1608Metric | https://yageogroup.com/content/datasheet/asset/file/PYU-RC_GROUP_51_ROHS_L | RC0603JR-070RL | 311-0.0GRCT-ND
RESET1 | 1 | KMR2 |  |  |  | Button_Switch_SMD:SW_Push_1P1T-SH_NO_CK_KMR2xxG | https://www.littelfuse.com/assetdocs/littelfuse-c-k-tactile-kmr2-series-datasheet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 | KMR221NG LFS | CKN10244CT-ND
U1 | 1 | BMD-340-A-R |  |  |  | smart_compass:RIGADO_BMD-340-A-R | https://content.u-blox.com/sites/default/files/BMD-340_DataSheet_UBX-19033353.pdf | BMD-340-A-R | 672-BMD-340-A-RCT-ND
U2 | 1 | S25FL064LABNFI043 |  |  |  | smart_compass:SON80P400X400X60-9N | https://www.infineon.com/assets/row/public/documents/10/49/infineon-s25fl064l-64-mbit-8-mbyte-3-datasheet-en.pdf | S25FL064LABNFI043 | 448-S25FL064LABNFI043CT-ND
U3 | 1 | RT9080-33GJ5 |  |  |  | smart_compass:SOT94P280X100-5N | https://www.richtek.com/SaveDownload.aspx?specid=RT9080 | RT9080-33GJ5 | 1028-1509-1-ND
U4 | 1 | MCP73831T-2ACI_OT |  |  |  | smart_compass:SOT95P280X145-5N | https://ww1.microchip.com/downloads/aemDocuments/documents/APID/ProductDocuments/DataSheets/MCP73831-Family-Data-Sheet-DS20001984H.pdf | MCP73831T-2ACI/OT | MCP73831T-2ACI/OTCT-ND
U5 | 1 | MAX17048G_T10 |  |  |  | smart_compass:SON50P200X200X80-9N | https://www.analog.com/media/en/technical-documentation/data-sheets/MAX17048-MAX17049.pdf | MAX17048G+T10 | MAX17048G+T10CT-ND
U6 | 1 | BNO086 |  |  |  | smart_compass:IC_BNO086 | https://www.ceva-ip.com/wp-content/uploads/BNO080_085-Datasheet.pdf | BNO086 | 1888-BNO086CT-ND
U7 | 1 | DRV2605LDGSR |  |  |  | smart_compass:SOP50P490X110-10N | https://www.ti.com/lit/ds/symlink/drv2605l.pdf?HQS=dis-dk-null-digikeymode-dsf-pf-null-wwe&ts=1780420623353 | DRV2605LDGSR | 296-40032-1-ND
U8 | 1 | MAX-M10S-00B |  |  |  | smart_compass:XCVR_MAX-M10S-00B | https://content.u-blox.com/sites/default/files/MAX-M10S_DataSheet_UBX-20035208.pdf | MAX-M10S-00B | 672-MAX-M10S-00BCT-ND
X1 | 1 | USB4085-GF-A |  |  |  | smart_compass:GCT_USB4085-GF-A_REVA4 | https://gct.co/files/specs/usb4085-spec.pdf | USB4085-GF-A | 2073-USB4085-GF-ACT-ND
Y1 | 1 | 32.768KHZ |  |  |  | smart_compass:XTAL_ABS07-32.768KHZ-7-T | https://abracon.com/Resonators/ABS07.pdf | ABS07-32.768KHZ-7-T | 535-9543-1-ND

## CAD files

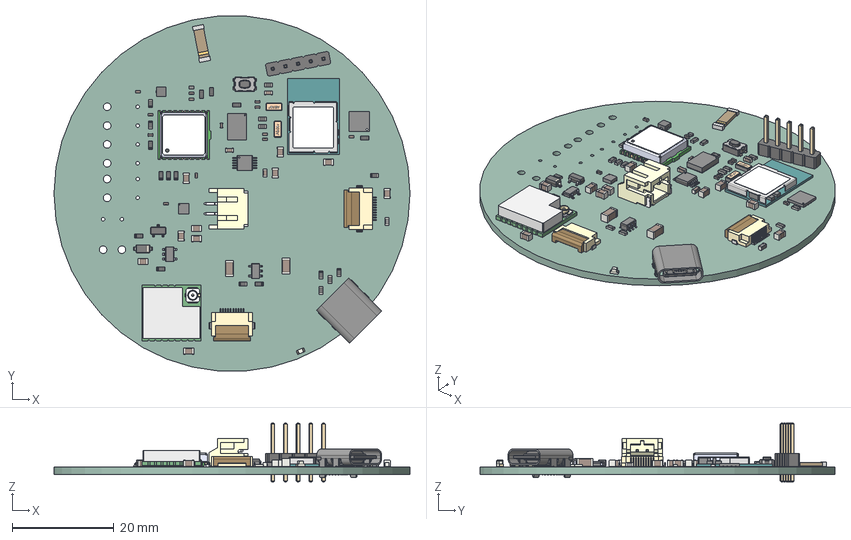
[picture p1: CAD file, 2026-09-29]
boards/main/main.step
70.0 x 69.8 x 11.5 mm
S2B-PH-SM4-TB(LF)(SN)
R_0603_1608Metric x 22
MAX17048G+T10
SOT-23
C_0805_2012Metric x 10
S25FL064LABNFI043
C_0402_1005Metric x 13
C_1206_3216Metric x 2
C_0603_1608Metric x 3
ABS07 x 2
DPY2
L_0603_1608Metric
BNO085
lock x 2
pins x 2
MAX-M10S-00B
BMD-340-A-R
MCP73831T-2ACI_OT
PinHeader_1x05_P254mm_Vertical
User_Library-IPEX
Extruded
SW_Push_1P1T-SH_NO_CK_KMR2xxG
RT9080-xGJ
D_SOD-123
Body001 (Mirror #1) x 5
XY-plane x 12
X-axis x 12
USB_C_Receptacle_GCT_USB4085
LED_0603_1608Metric
SmartCompass_PCB

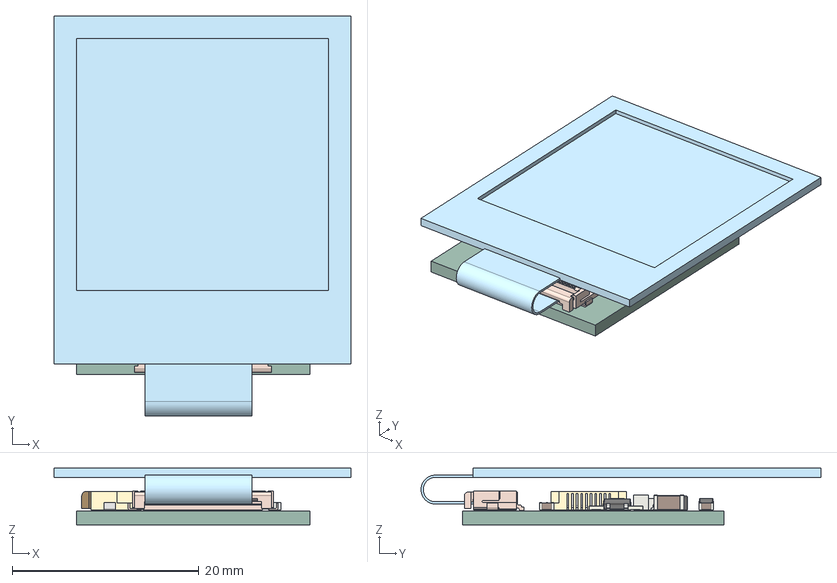
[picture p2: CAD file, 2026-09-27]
boards/display/Display.step
31.8 x 42.9 x 6.09 mm
C_0603_1608Metric x 8
D_SOD-123 x 3
C_0805_2012Metric
FH12-24S-0.5SH_Èª
R_0603_1608Metric x 2
C_1206_3216Metric x 2
L_APV_ANR3015
SOT-23
lock
pins
Display_PCB

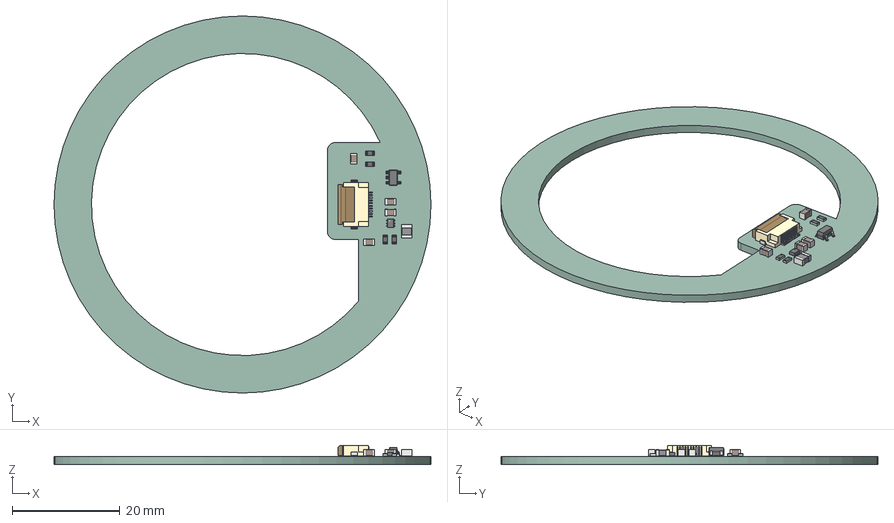
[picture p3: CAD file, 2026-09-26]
boards/led_ring/LedRing.step
70.0 x 70.0 x 3.59 mm
L_1008_2520Metric
R_0603_1608Metric x 4
C_0805_2012Metric x 4
SOT-23-5
lock
pins
SOT_563
LedRing_PCB

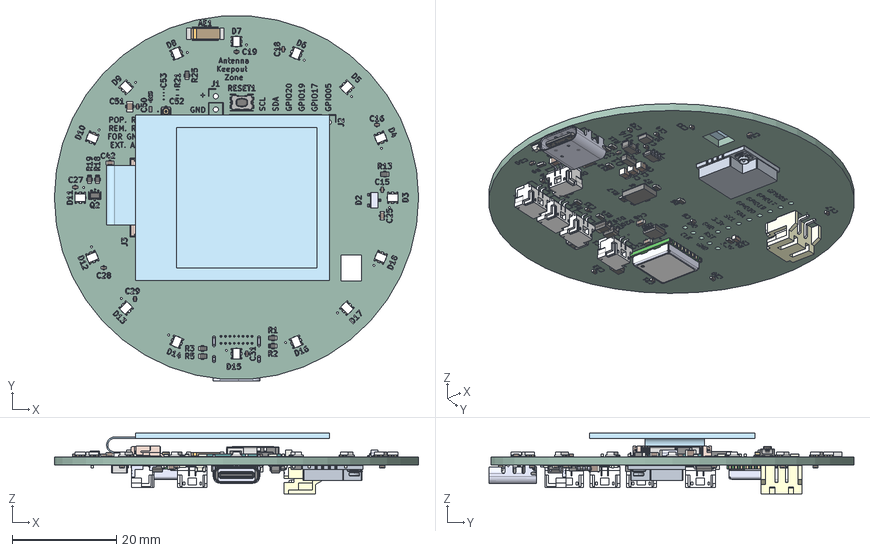
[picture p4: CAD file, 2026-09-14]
boards/main/SmartCompass.step
70.0 x 70.1 x 11.7 mm
WS2812B2020 x 16
R_0603_1608Metric x 23
C_0805_2012Metric x 7
C_0402_1005Metric x 30
C_0603_1608Metric x 12
SW_Push_1P1T-SH_NO_CK_KMR2xxG
Body_Solid1
Body002_Solid1
Array002_Solid1 x 4
Array003_Solid2 x 3
Body003_Solid1
Body004_Solid1
e-ink_1.54in
FH12-24S-0.5SH_Èª
ABS07-32.768KHZ-7-T
BMD-340-A-R
MMBT3904--3DModel-STEP-711646
SOT-323_SC-70
RECE.20369.001E.01
ANT_1575AT_JOT
TPD1E05U06DPYR
D_SOD-123 x 4
Body001 (Mirror #1) x 5
XY-plane x 12
X-axis x 12
BCW31_BCW31
SMxB-GHS-TB_02 x 5
pin x 10
RT9080-33GJ5
USB4085-GF-A
MAX-M10S-00B
S2B-PH-SM4-TB -LF--SN---3DModel-STEP-269445
LED_0603_1608Metric
MCP73831T-2ACI_OT
BNO085
SmartCompass 1.109.1
MAX17048G_T10
IND_TAIYO_NR3015_TAY
SmartCompass_silkscreen x 2
SmartCompass_PCB

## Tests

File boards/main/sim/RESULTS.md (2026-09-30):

# Main board simulation results

Results of the transient scenario in [README.md](README.md), run on 2026-09-30.
Since the previous run, the 10 uF capacitor by the MCU's VBUS pin has come off
the board, and the LED ring's load now pulses at the LEDs' 1 kHz PWM instead of
drawing steady power.

The run before that, on 2026-09-29, followed three changes to the power path:
the pull-down on the load-sharing FET's gate went from 100k to 4.7k, the VBUS
Schottky went from a 0.5 A MBR0540 to a 1 A SS1040-AU, and a second SS1040-AU
went in across the load-sharing FET, from the cell to VSYS.

## Cases

The scenario was run as it stands and with the `.param` values below changed.
Full white is every LED on the ring at full brightness. 3.4 V is a nearly flat
cell.

| Case | `VBAT` | `RING_W` |
| ---- | --- | --- |
| Nominal | 3.7 V | 0.45 W |
| Full white | 3.7 V | 1.4 W |
| Low cell | 3.4 V | 0.45 W |
| Low cell, full white | 3.4 V | 1.4 W |
| Full cell, full white | 4.2 V | 1.4 W |

`RING_W` is the ring's average draw. At 0.45 W the ring pulses between
0.05 W and the full-white 1.4 W, on for 30% of each millisecond. Full white
is steady.

The plug-in was also run on its own with a 20 ns step, because the 10 us step
of the main scenario is too coarse for the cable ringing. For that run the
cable goes in at 5 ms with the ring already on, and nothing else happens.

## Summary

| Area | Verdict |
| ---- | --- |
| Plugging in | Fine |
| Running on battery | Fine |
| Running on USB | Fine, but the ring's pulses take it over 500 mA at any brightness |
| Unplugging | Fine |

## Plugging in

| Case | VBUS peak | VSYS peak |
| ---- | --- | --- |
| Nominal | 5.20 V | 4.64 V |
| Low cell, full white | 4.95 V | 4.50 V |

The ringing on VBUS is gone within about 55 us. After that VBUS steps by about
60 mV with each ring pulse, from the cable's resistance. VBUS is well under
the nRF52840's 5.8 V limit on its VBUS pin, and everything behind the Schottky
sees less than 4.7 V. The 3.3 V rail does not move.

The ideal source and 0.2 ohm cable give an inrush peak of about 7.9 A for a
few microseconds, down from 11.5 A with the 10 uF capacitor on VBUS. Up to
3.4 A goes through the ring's ferrite bead, over its 1 A rating for about
30 us. A real host limits this, and both parts survive pulses like that.

## Running on battery

| Case | VSYS min | 3.3 V min | Cell current max |
| ---- | --- | --- | --- |
| Nominal | 3.60 V | 3.30 V | 548 mA |
| Full white | 3.60 V | 3.30 V | 548 mA |
| Low cell | 3.29 V | 3.21 V | 587 mA |
| Low cell, full white | 3.29 V | 3.21 V | 587 mA |

The nominal cases now reach the same minimums and peaks as full white,
because each ring pulse is at full-white power. On average they draw what
they did before.

With a low cell the LDO runs in dropout and the 3.3 V rail follows the cell,
but it stays well clear of the 2.7 V that the GNSS module and QSPI flash need.

The ring's pulses put a 1 kHz ripple on the supply: 110 mV peak to peak on
`Vdrive` (120 mV with a low cell) and 70 to 80 mV on VSYS. There is no
ringing, and the ferrite bead peaks at 430 mA, within its 1 A rating. In the
simulation the 3.3 V rail only sees it with a low cell, where the LDO is in
dropout, and then only 4 mV. The LDO model has no supply rejection. The
RT9080's 75 dB at 1 kHz would take 80 mV on VSYS down to about 15 uV on the
3.3 V rail.

## Running on USB

| Case | USB current, average | USB current, peak | VBUS Schottky current, peak |
| ---- | --- | --- | --- |
| Nominal | 393 mA | 731 mA | 472 mA |
| Full white | 610 mA | 731 mA | 472 mA |
| Full cell, full white | 350 mA | 470 mA | 468 mA |

In the nominal case each ring pulse takes the USB current to 610 mA. The
731 mA peaks are a ring pulse during the LoRa transmission. A haptic buzz at
the same time adds about 60 mA, which keeps the VBUS Schottky at around half
its 1 A rating. The charger delivers 256 mA until the cell is full. VBUS at
the connector stays above 4.84 V through the 0.2 ohm cable, and the 3.3 V
rail holds at 3.30 V.

The 4.7k pull-down costs about 1 mA from USB and nothing on battery. On
battery, the only current through it is the VBUS Schottky's reverse leakage,
which does not depend on the resistor.

## Unplugging

| Case | VSYS min | 3.3 V min | Time under 3.2 V | Time under 2.7 V |
| ---- | --- | --- | --- | --- |
| Nominal | 3.19 V | 3.17 V | 0.6 ms | 0 |
| Full white | 3.19 V | 3.16 V | 3.6 ms | 0 |
| Low cell | 2.87 V | 2.85 V | 6.2 ms | 0 |
| Low cell, full white | 2.87 V | 2.85 V | 16.5 ms | 0 |
| Full cell, full white | 3.71 V | 3.30 V | 0 | 0 |

The load-sharing FET only turns on once VBUS has fallen about 0.55 V below
VSYS. The capacitance on VBUS drains quickly into the loads until the VBUS
Schottky stops conducting. After that only the gate pull-down drains it, which
takes a few milliseconds with 4.7k. Until the FET turns on, the cell feeds VSYS
through the Schottky across the FET.

The dips are much shorter than in the previous run (16.5 ms under 3.2 V for
the low cell, full white case, against 93 ms), because there is less
capacitance on VBUS to drain. The nominal and low cell cases now bottom out as
low as full white, because the ring's pulses are at full-white power. They
spend less time there because the ring is dark for most of each millisecond.

Without the parallel Schottky, the cell fed VSYS through the FET's body diode,
which drops about 0.65 V against the Schottky's 0.45 V. With the old 100k
pull-down, the nominal case sat at 2.93 V for 119 ms. With 4.7k and no
parallel Schottky, the low cell, full white case went under 2.7 V for 10 ms.

The rail bottoms out at 2.85 V. The parallel Schottky carries about 0.6 A for
that time, within its 1 A rating.

## Outstanding

1. **USB current budget.** On USB the board draws more than the 500 mA a
   USB 2.0 port has to supply, in pulses at any ring brightness and on
   average with the ring bright. The CC resistors don't tell the firmware
   what the source can supply. The height of a pulse depends on how many
   colour channels are lit, not on their brightness, so dimming the ring in
   firmware lowers the average but not the peaks. Lighting fewer channels at
   once, or lowering the charge current, lowers both.

## Caveats

The ring's LEDs are assumed to switch in step. Real ones drift in and out of
step, so the full-height pulses come and go rather than arriving every
millisecond.

The MLCCs' loss of capacitance with DC bias is not modelled. Less capacitance
on VBUS makes the unplug dip shorter. Less on VSYS and the 3.3 V rail makes it
deeper. The nRF52840's VBUS pin is assumed to draw 1 uA. See
[README.md](README.md) for the rest.

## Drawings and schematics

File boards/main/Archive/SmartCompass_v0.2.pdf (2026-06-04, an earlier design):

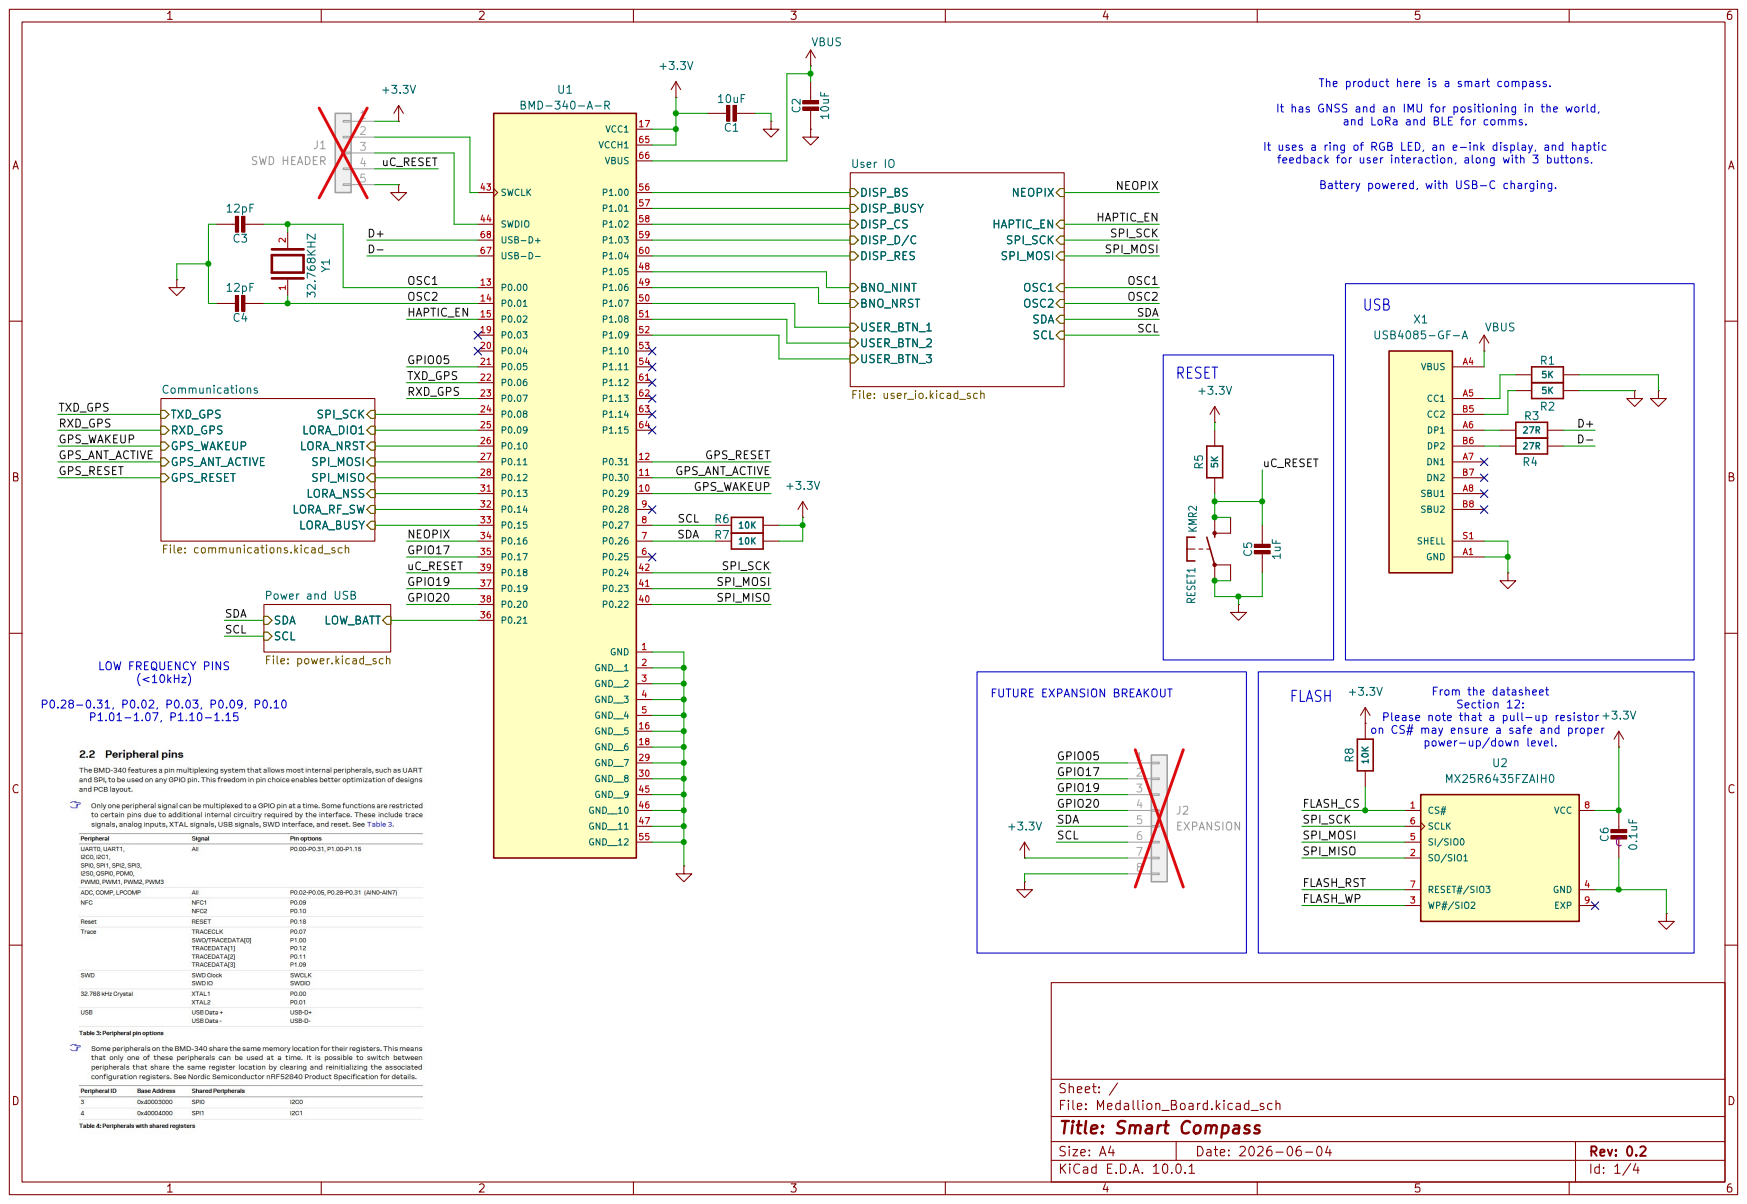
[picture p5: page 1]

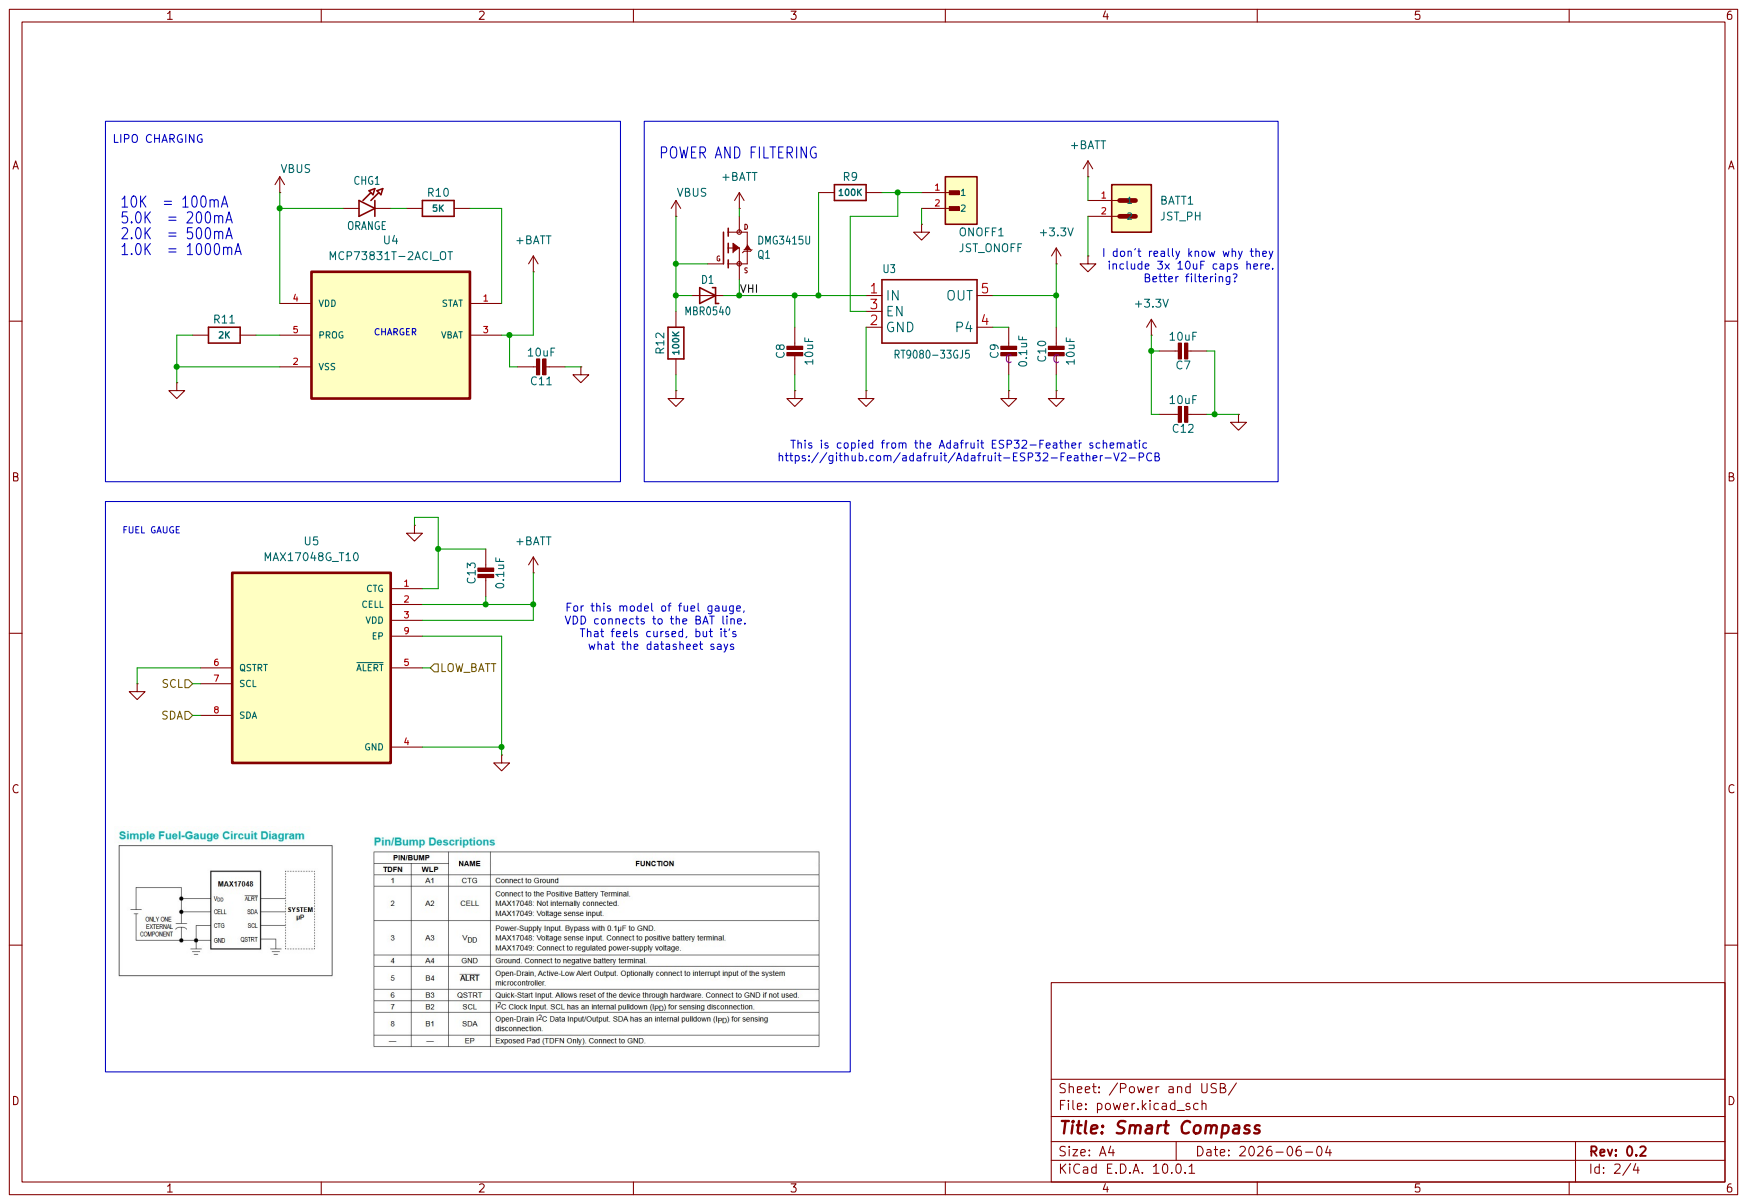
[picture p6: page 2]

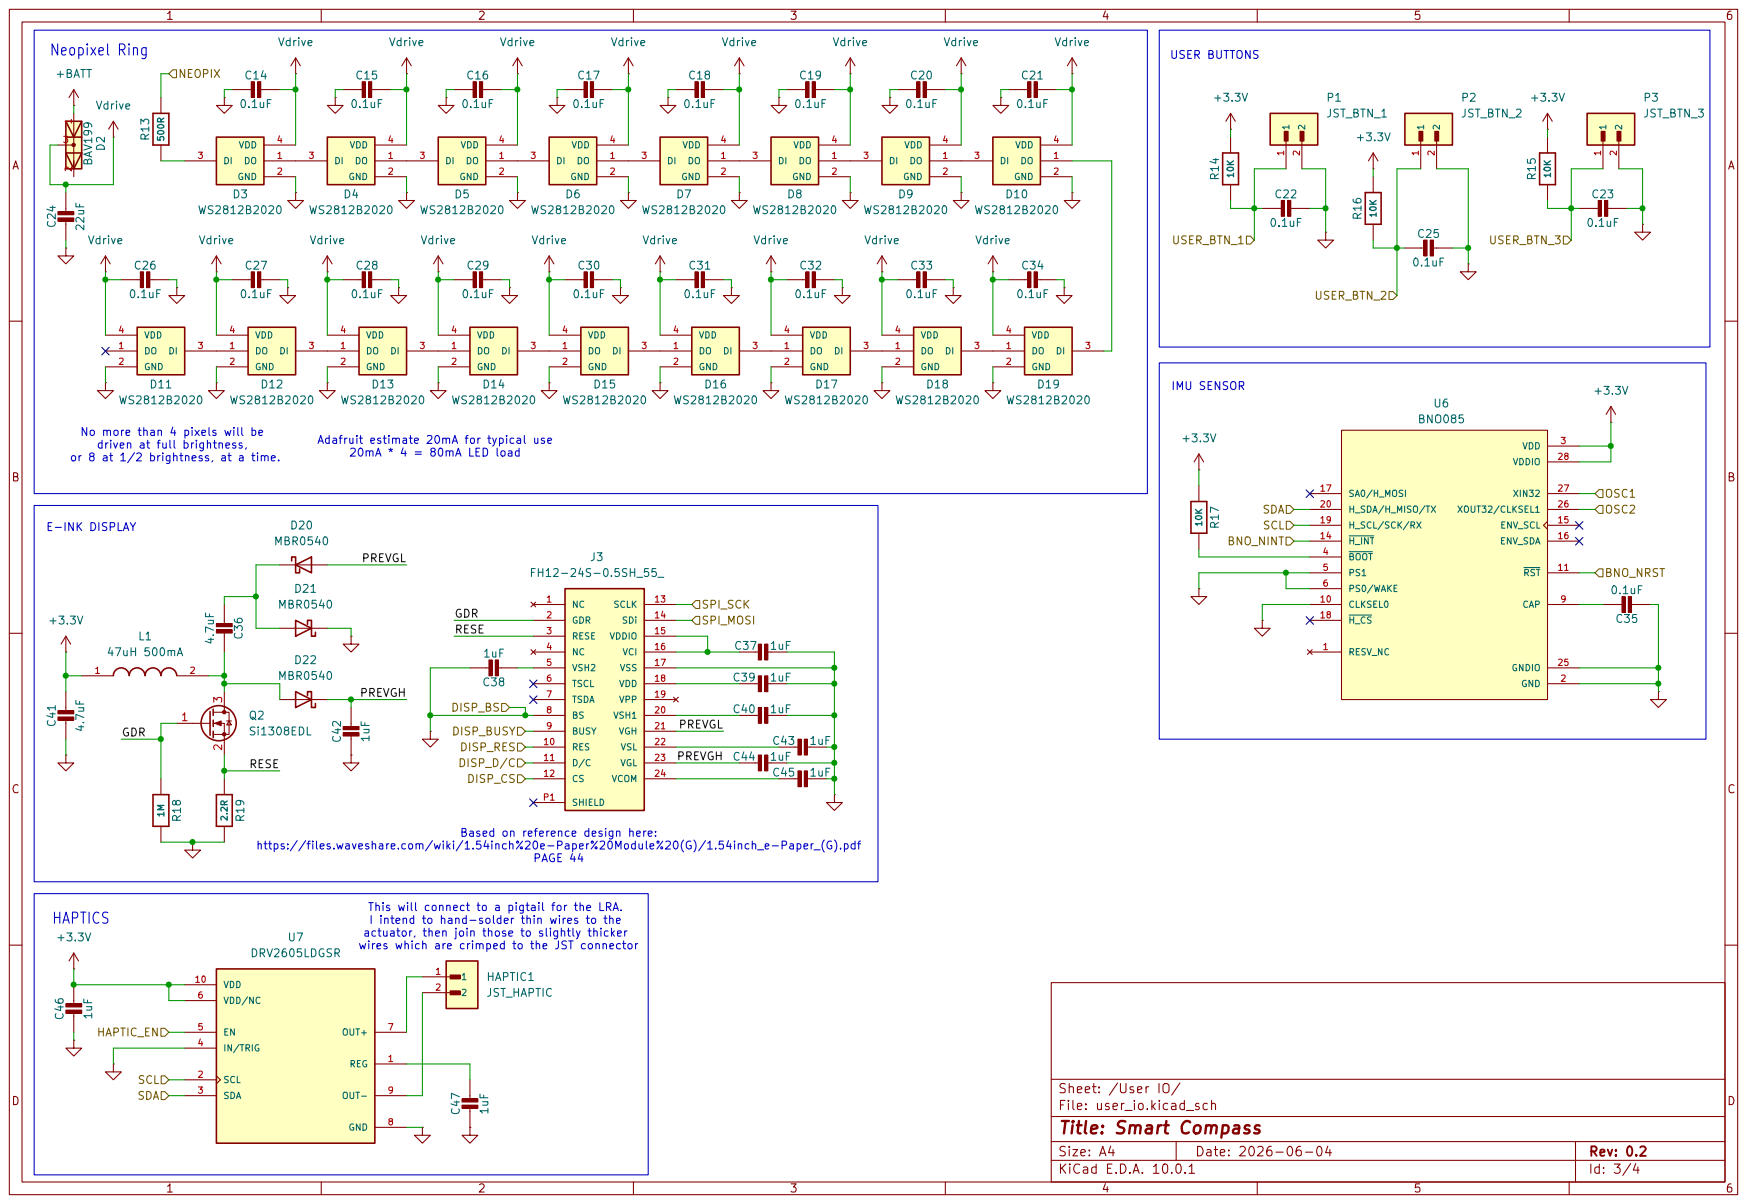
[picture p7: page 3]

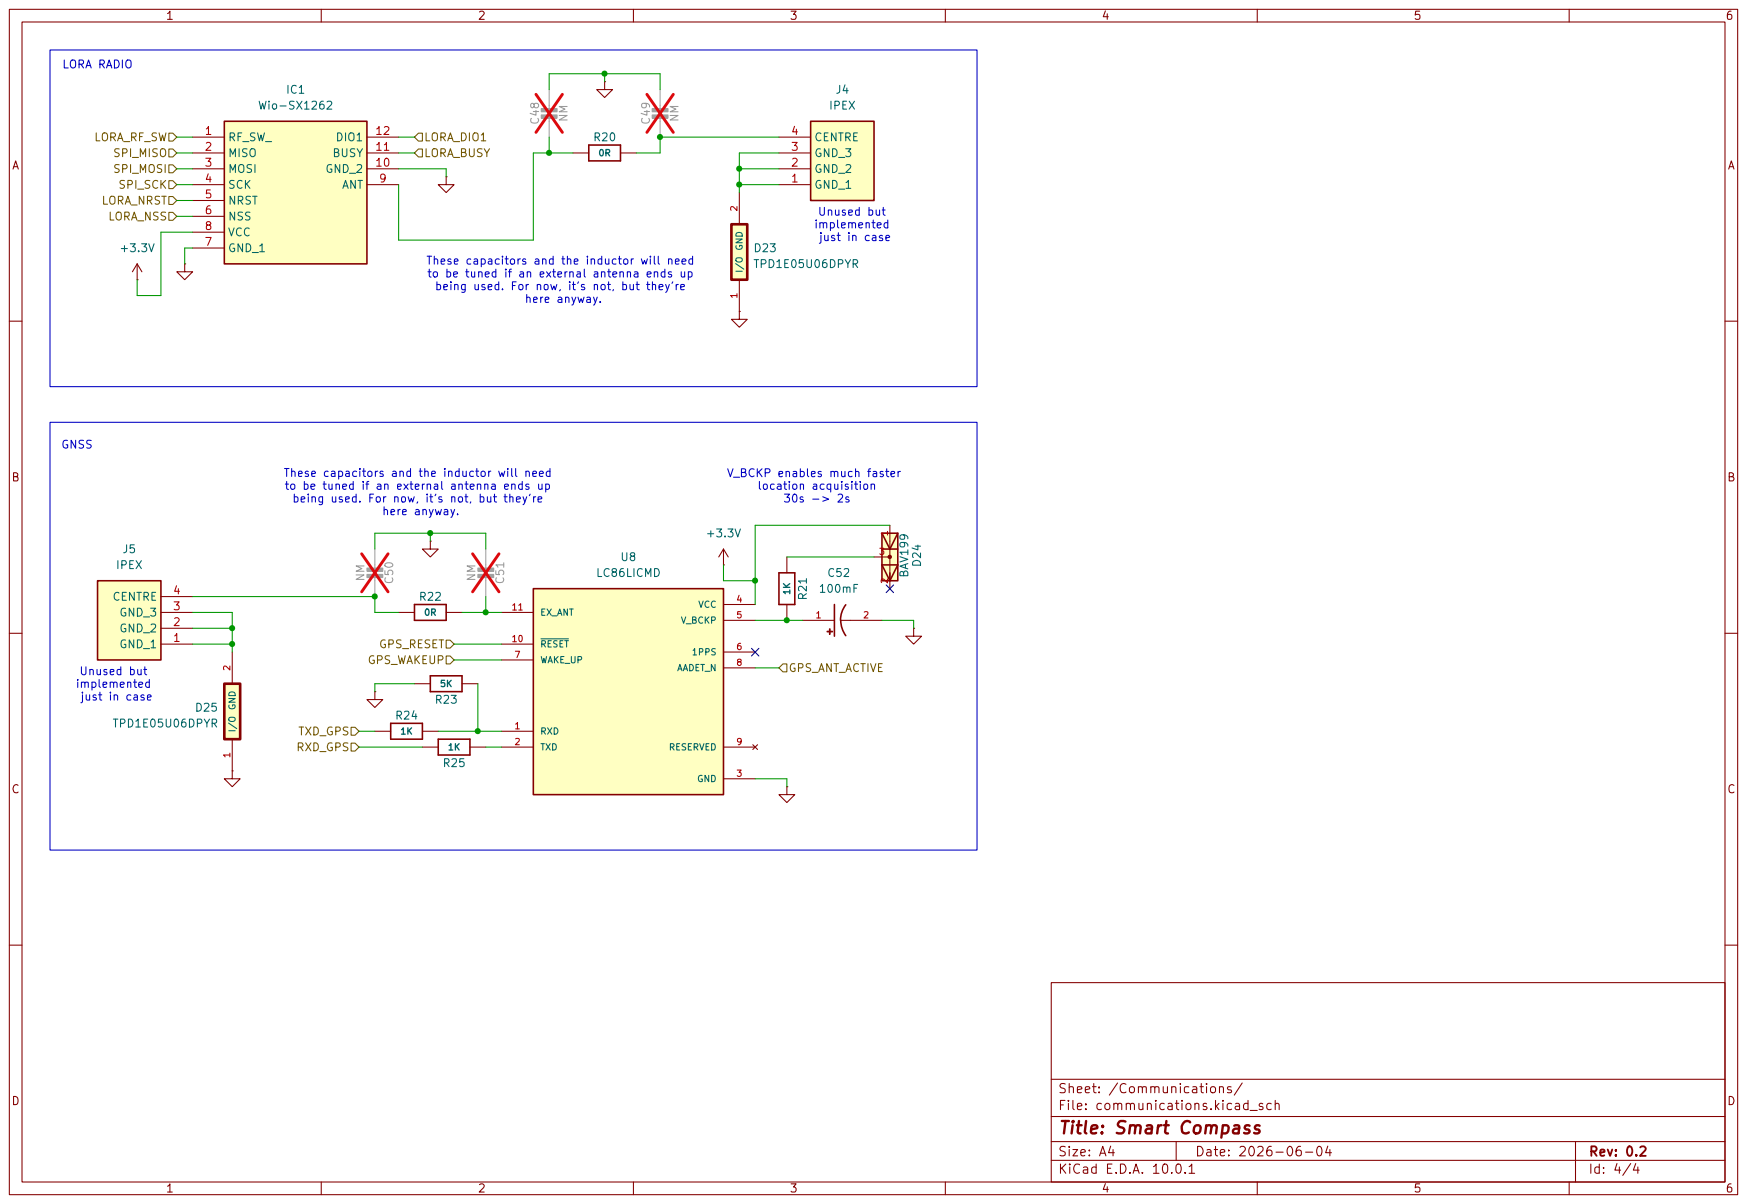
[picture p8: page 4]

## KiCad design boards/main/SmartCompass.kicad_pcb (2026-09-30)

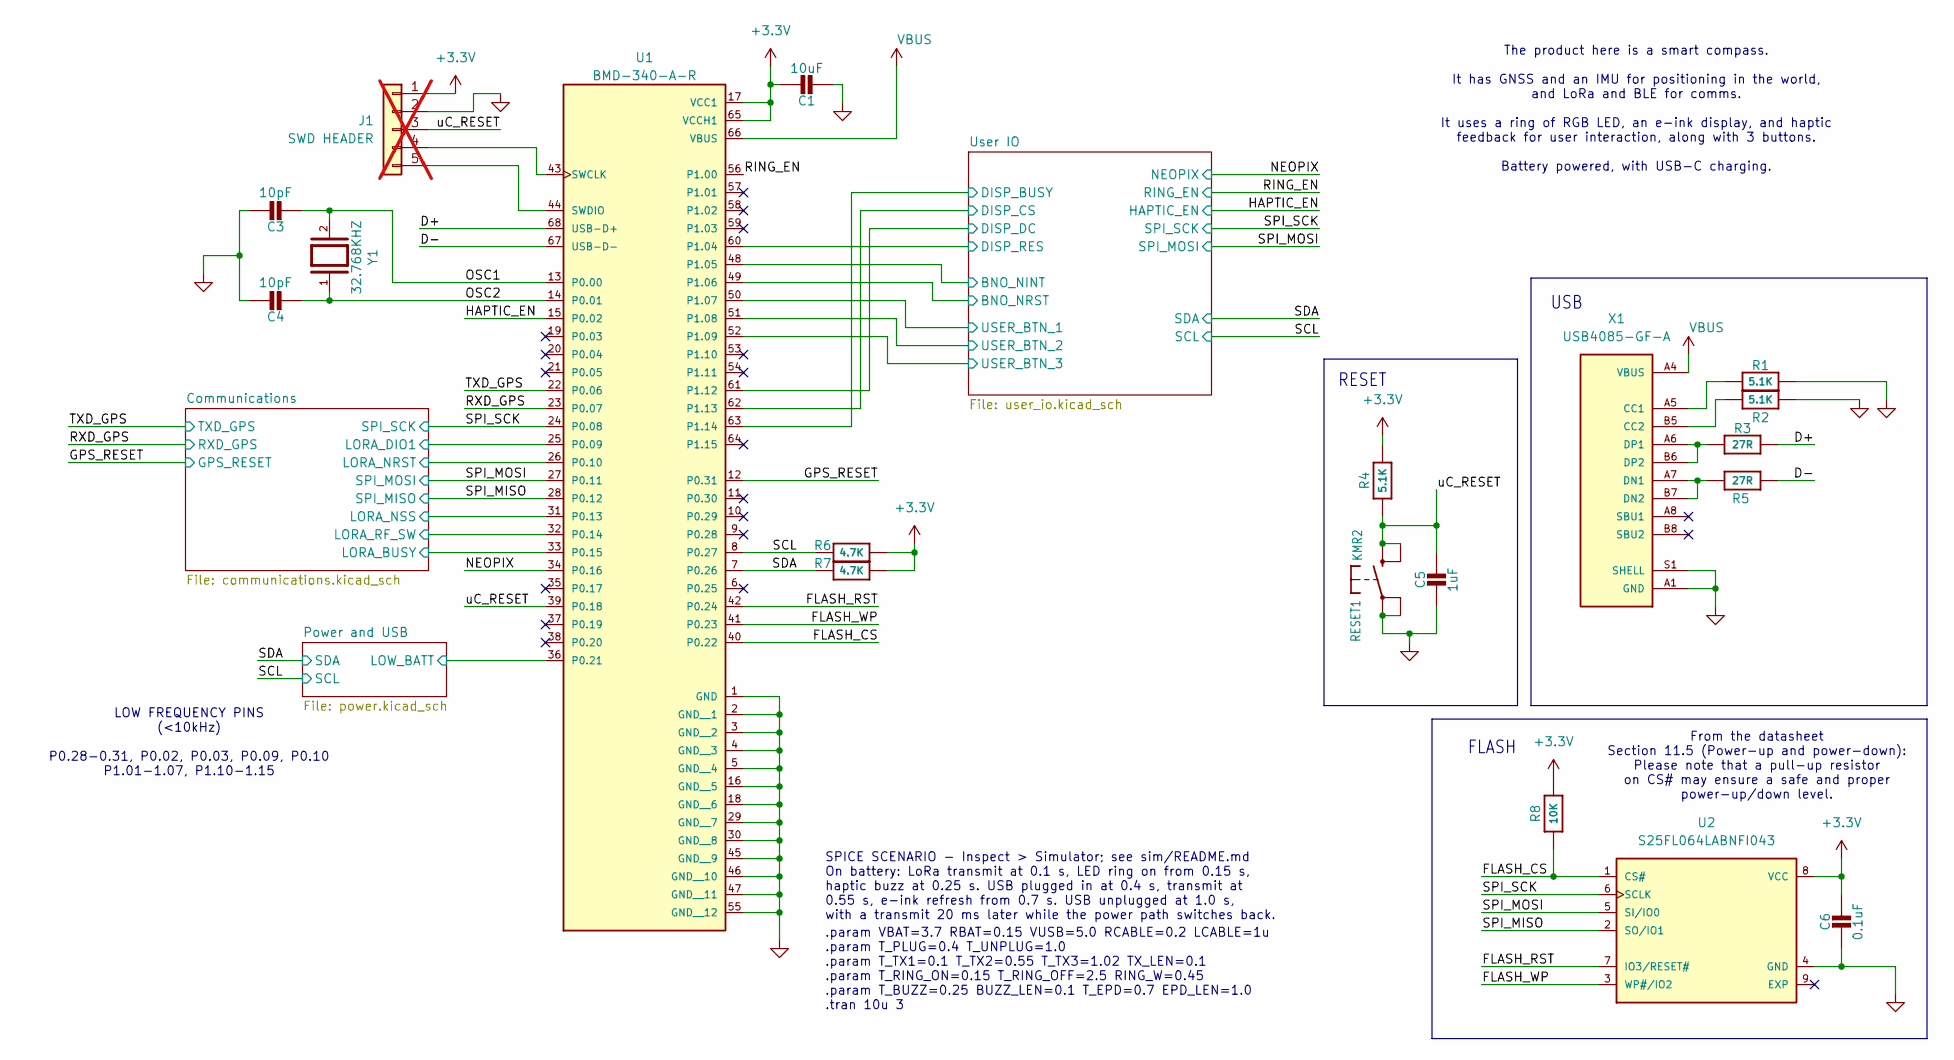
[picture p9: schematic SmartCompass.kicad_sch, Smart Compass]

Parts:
C1: 10uF; C_0805_2012Metric; Voltage 10V; MPN CGA4J3X5R1A106K125AB; DigiKey_PN 445-6970-1-ND
C3, C4: 10pF; C_0402_1005Metric; Voltage 50V; MPN CL05C100JB5NNNC; DigiKey_PN 1276-1139-1-ND
C5: 1uF; C_0603_1608Metric; Voltage 50V; Tolerance 10%; MPN C1608X7R1H105K080AB; DigiKey_PN 445-C1608X7R1H105K080ABCT-ND
C6: 0.1uF; C_0402_1005Metric; Voltage 16V; MPN CL05B104KO5VPNC; DigiKey_PN 1276-6844-1-ND
J1: SWD HEADER; PinHeader_1x05_P2.54mm_Vertical; not fitted
R1, R2, R4: 5.1K; R_0603_1608Metric; Tolerance 1%; MPN ERJ-3EKF5101V; DigiKey_PN P5.10KHCT-ND
R3, R5: 27R; R_0603_1608Metric; Tolerance 1%; MPN RC0603FR-0727RL; DigiKey_PN 311-27.0HRCT-ND
R6, R7: 4.7K; R_0603_1608Metric; Tolerance 1%; MPN RC0603FR-074K7L; DigiKey_PN 311-4.70KHRCT-ND
R8: 10K; R_0603_1608Metric; Tolerance 1%; MPN RC0603FR-0710KL; DigiKey_PN 311-10.0KHRCT-ND
RESET1: KMR2; SW_Push_1P1T-SH_NO_CK_KMR2xxG; MPN KMR221NG LFS; DigiKey_PN CKN10244CT-ND
U1: BMD-340-A-R; RIGADO_BMD-340-A-R; MPN BMD-340-A-R; DigiKey_PN 672-BMD-340-A-RCT-ND
U2: S25FL064LABNFI043; SON80P400X400X60-9N; MPN S25FL064LABNFI043; DigiKey_PN 448-S25FL064LABNFI043CT-ND
X1: USB4085-GF-A; GCT_USB4085-GF-A_REVA4; MPN USB4085-GF-A; DigiKey_PN 2073-USB4085-GF-ACT-ND
Y1: 32.768KHZ; XTAL_ABS07-32.768KHZ-7-T; PARTREV 08.19.15; DigiKey_PN 535-9543-1-ND

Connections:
+3.3V: C1.1, C6.1, J1.1, R4.2, R6.1, R7.1, R8.2, U1.17 (VCC1), U1.65 (VCCH1), U2.8 (VCC); also elsewhere on the board
/Communications/LORA_BUSY: U1.33 (P0.15); also elsewhere on the board
/Communications/LORA_DIO1: U1.25 (P0.09); also elsewhere on the board
/Communications/LORA_NRST: U1.26 (P0.10); also elsewhere on the board
/Communications/LORA_NSS: U1.31 (P0.13); also elsewhere on the board
/Communications/LORA_RF_SW: U1.32 (P0.14); also elsewhere on the board
/D+: R3.1, U1.68 (USB-D+)
/D-: R5.1, U1.67 (USB-D-)
/FLASH_CS: R8.1, U1.40 (P0.22), U2.1 (CS#)
/FLASH_RST: U1.42 (P0.24), U2.7 (IO3/RESET#)
/FLASH_WP: U1.41 (P0.23), U2.3 (WP#/IO2)
/GPS_RESET: U1.12 (P0.31); also elsewhere on the board
/HAPTIC_EN: U1.15 (P0.02); also elsewhere on the board
/NEOPIX: U1.34 (P0.16); also elsewhere on the board
/OSC1: C3.2, U1.13 (P0.00), Y1.2
/OSC2: C4.2, U1.14 (P0.01), Y1.1
/Power and USB/LOW_BATT: U1.36 (P0.21); also elsewhere on the board
/RING_EN: U1.56 (P1.00); also elsewhere on the board
/RXD_GPS: U1.23 (P0.07); also elsewhere on the board
/SCL: R6.2, U1.8 (P0.27); also elsewhere on the board
/SDA: R7.2, U1.7 (P0.26); also elsewhere on the board
/SPI_MISO: U1.28 (P0.12), U2.2 (SO/IO1); also elsewhere on the board
/SPI_MOSI: U1.27 (P0.11), U2.5 (SI/IO0); also elsewhere on the board
/SPI_SCK: U1.24 (P0.08), U2.6 (SCLK); also elsewhere on the board
/TXD_GPS: U1.22 (P0.06); also elsewhere on the board
/User IO/BNO_NINT: U1.48 (P1.05); also elsewhere on the board
/User IO/BNO_NRST: U1.49 (P1.06); also elsewhere on the board
/User IO/DISP_BUSY: U1.63 (P1.14); also elsewhere on the board
/User IO/DISP_CS: U1.62 (P1.13); also elsewhere on the board
/User IO/DISP_DC: U1.61 (P1.12); also elsewhere on the board
/User IO/DISP_RES: U1.60 (P1.04); also elsewhere on the board
/User IO/USER_BTN_1: U1.50 (P1.07); also elsewhere on the board
/User IO/USER_BTN_2: U1.51 (P1.08); also elsewhere on the board
/User IO/USER_BTN_3: U1.52 (P1.09); also elsewhere on the board
/uC_RESET: C5.1, J1.3, R4.1, RESET1.2, U1.39 (P0.18)
GND: C1.2, C3.1, C4.1, C5.2, C6.2, J1.2, R1.1, R2.1, RESET1.1, U1.1 (GND), U1.2 (GND__1), U1.3 (GND__2), U1.4 (GND__3), U1.5 (GND__4), U1.16 (GND__5), U1.18 (GND__6), U1.29 (GND__7), U1.30 (GND__8), U1.45 (GND__9), U1.46 (GND__10), U1.47 (GND__11), U1.55 (GND__12), U2.4 (GND), X1.A1 (GND), X1.A12 (GND), X1.B1 (GND), X1.B12 (GND), X1.S1 (SHELL), X1.S2 (SHELL), X1.S3 (SHELL), X1.S4 (SHELL); also elsewhere on the board
unnamed: J1.4, U1.43 (SWCLK)
unnamed: J1.5, U1.44 (SWDIO)
unnamed: R1.2, X1.A5 (CC1)
unnamed: R2.2, X1.B5 (CC2)
unnamed: R5.2, X1.A7 (DN1), X1.B7 (DN2)
unnamed: R3.2, X1.A6 (DP1), X1.B6 (DP2)
VBUS: U1.66 (VBUS), X1.A4 (VBUS), X1.A9 (VBUS), X1.B4 (VBUS), X1.B9 (VBUS); also elsewhere on the board

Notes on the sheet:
From the datasheet Section 11.5 (Power-up and power-down): Please note that a pull-up resistor on CS# may ensure a safe and proper power-up/down level.
FLASH
The product here is a smart compass. It has GNSS and an IMU for positioning in the world, and LoRa and BLE for comms. It uses a ring of RGB LED, an e-ink display, and haptic feedback for user interaction, along with 3 buttons. Battery powered, with USB-C charging.
LOW FREQUENCY PINS (<10kHz) P0.28-0.31, P0.02, P0.03, P0.09, P0.10 P1.01-1.07, P1.10-1.15
RESET
SPICE SCENARIO - Inspect > Simulator; see sim/README.md On battery: LoRa transmit at 0.1 s, LED ring on from 0.15 s, haptic buzz at 0.25 s. USB plugged in at 0.4 s, transmit at 0.55 s, e-ink refresh from 0.7 s. USB unplugged at 1.0 s, with a transmit 20 ms later while the power path switches back.
USB
.param VBAT=3.7 RBAT=0.15 VUSB=5.0 RCABLE=0.2 LCABLE=1u .param T_PLUG=0.4 T_UNPLUG=1.0 .param T_TX1=0.1 T_TX2=0.55 T_TX3=1.02 TX_LEN=0.1 .param T_RING_ON=0.15 T_RING_OFF=2.5 RING_W=0.45 .param T_BUZZ=0.25 BUZZ_LEN=0.1 T_EPD=0.7 EPD_LEN=1.0 .tran 10u 3

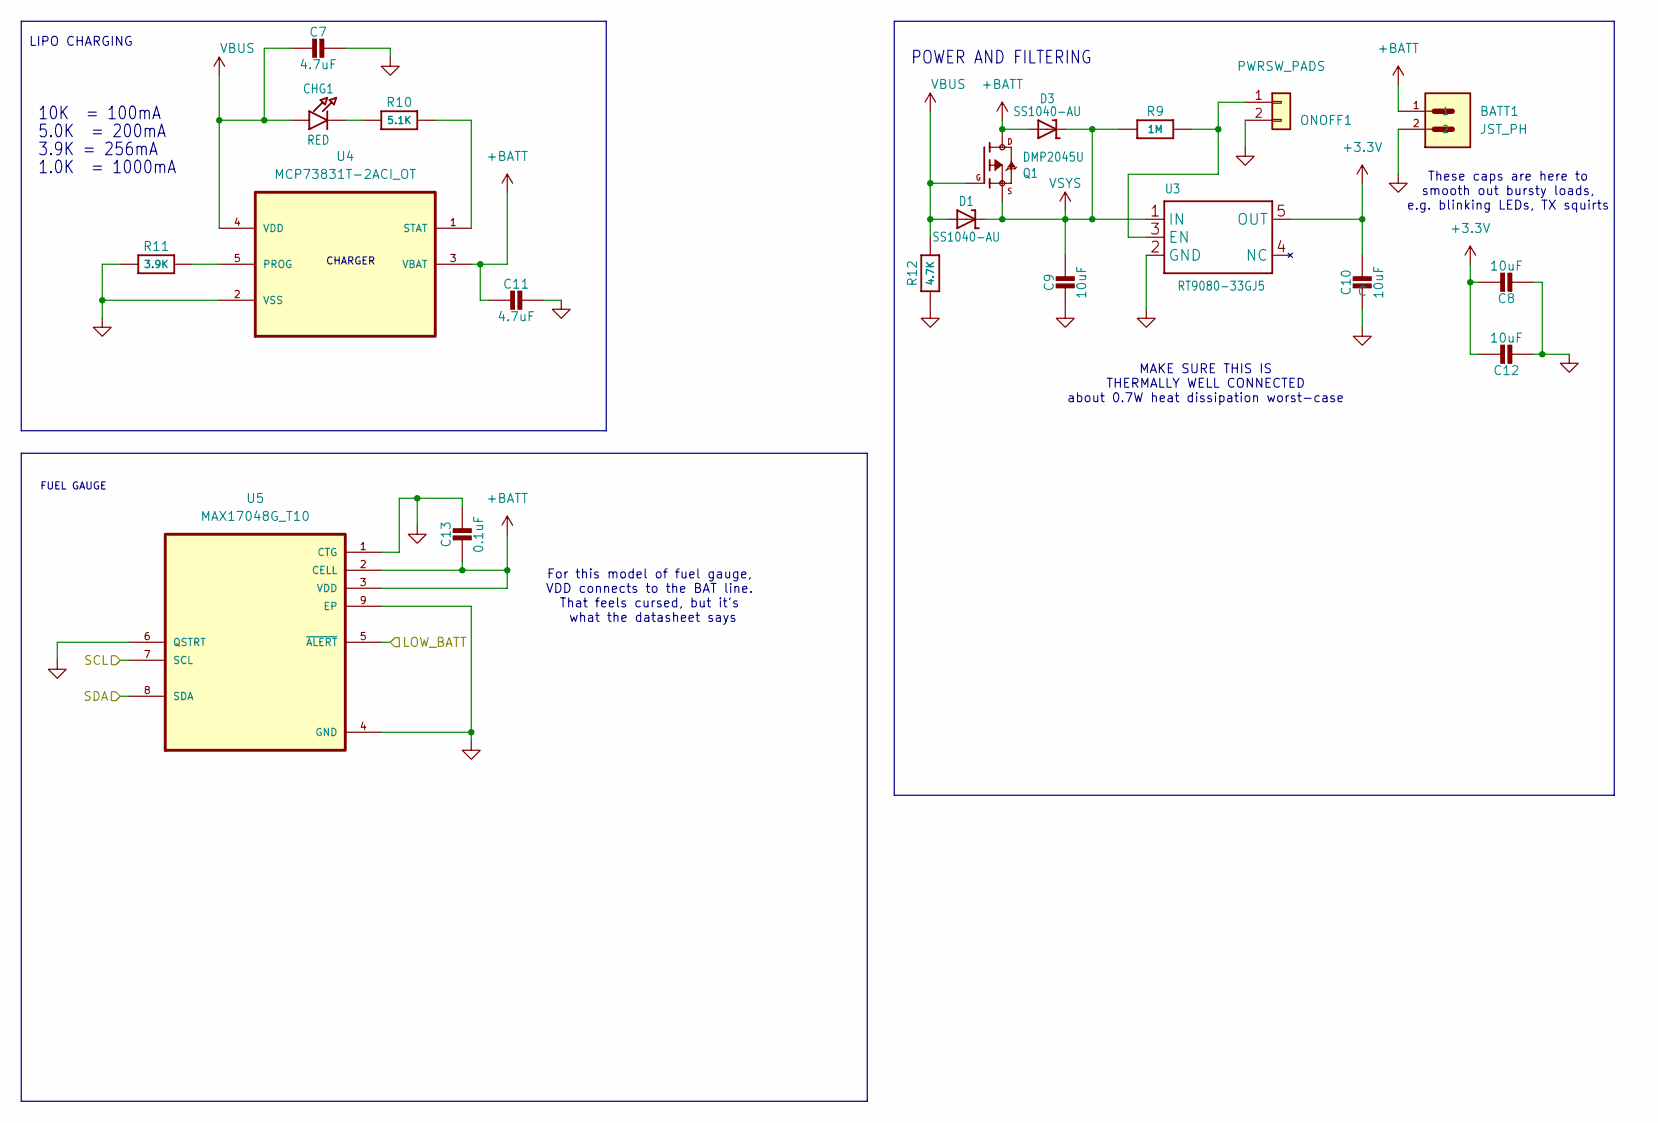
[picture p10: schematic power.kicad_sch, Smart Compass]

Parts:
BATT1: JST_PH; JST_S2B-PH-SM4-TB; MPN S2B-PH-SM4-TB; DigiKey_PN 455-S2B-PH-SM4-TBCT-ND
C7, C11: 4.7uF; C_1206_3216Metric; Voltage 50V; Tolerance 10%; MPN CL31B475KBHNFNE; DigiKey_PN 1276-3179-1-ND
C8, C9, C10, C12: 10uF; C_0805_2012Metric; Voltage 10V; MPN CGA4J3X5R1A106K125AB; DigiKey_PN 445-6970-1-ND
C13: 0.1uF; C_0402_1005Metric; Voltage 16V; MPN CL05B104KO5VPNC; DigiKey_PN 1276-6844-1-ND
CHG1: RED; LED_0603_1608Metric; MPN LTST-C191KRKT; DigiKey_PN 160-1447-1-ND
D1, D3: SS1040-AU; D_SOD-123; MPN SS1040-AU_R1_000A1; DigiKey_PN 3757-SS1040-AU_R1_000A1CT-ND
ONOFF1: PWRSW_PADS; SolderWire-0.127sqmm_1x02_P3.7mm_D0.48mm_OD1mm_Relief
Q1: DMP2045U; SOT-23; MPN DMP2045U-7; DigiKey_PN DMP2045U-7DICT-ND
R9: 1M; R_0603_1608Metric; Tolerance 1%; MPN RC0603FR-071ML; DigiKey_PN 311-1.00MHRCT-ND
R10: 5.1K; R_0603_1608Metric; Tolerance 1%; MPN ERJ-3EKF5101V; DigiKey_PN P5.10KHCT-ND
R11: 3.9K; R_0603_1608Metric; Tolerance 1%; MPN RC0603FR-073K9L; DigiKey_PN 311-3.90KHRCT-ND
R12: 4.7K; R_0603_1608Metric; Tolerance 1%; MPN RC0603FR-074K7L; DigiKey_PN 311-4.70KHRCT-ND
U3: RT9080-33GJ5; SOT94P280X100-5N; MPN RT9080-33GJ5; DigiKey_PN 1028-1509-1-ND
U4: MCP73831T-2ACI_OT; SOT95P280X145-5N; MPN MCP73831T-2ACI/OT; DigiKey_PN MCP73831T-2ACI/OTCT-ND
U5: MAX17048G_T10; SON50P200X200X80-9N; MPN MAX17048G+T10; DigiKey_PN MAX17048G+T10CT-ND

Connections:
+3.3V: C8.1, C10.1, C12.1, U3.5 (OUT); also elsewhere on the board
+BATT: BATT1.1, C11.2, C13.2, D3.2 (A), Q1.3 (D), U4.3 (VBAT), U5.2 (CELL), U5.3 (VDD)
/Power and USB/LOW_BATT: U5.5 (~ALERT); also elsewhere on the board
/SCL: U5.7 (SCL); also elsewhere on the board
/SDA: U5.8 (SDA); also elsewhere on the board
GND: BATT1.2, C7.1, C8.2, C9.2, C10.2, C11.1, C12.2, C13.1, ONOFF1.2, R11.1, R12.2, U3.2 (GND), U4.2 (VSS), U5.1 (CTG), U5.4 (GND), U5.6 (QSTRT), U5.9 (EP); also elsewhere on the board
unnamed: CHG1.1, R10.1
unnamed: ONOFF1.1, R9.2, U3.3 (EN)
unnamed: R11.2, U4.5 (PROG)
unnamed: R10.2, U4.1 (STAT)
VBUS: C7.2, CHG1.2, D1.2 (A), Q1.1 (G), R12.1, U4.4 (VDD); also elsewhere on the board
VSYS: C9.1, D1.1 (K), D3.1 (K), Q1.2 (S), R9.1, U3.1 (IN); also elsewhere on the board

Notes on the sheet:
10K = 100mA
POWER AND FILTERING
CHARGER
1.0K = 1000mA
5.0K = 200mA
MAKE SURE THIS IS THERMALLY WELL CONNECTED about 0.7W heat dissipation worst-case
3.9K = 256mA
LIPO CHARGING
These caps are here to smooth out bursty loads, e.g. blinking LEDs, TX squirts
For this model of fuel gauge, VDD connects to the BAT line. That feels cursed, but it's what the datasheet says
FUEL GAUGE

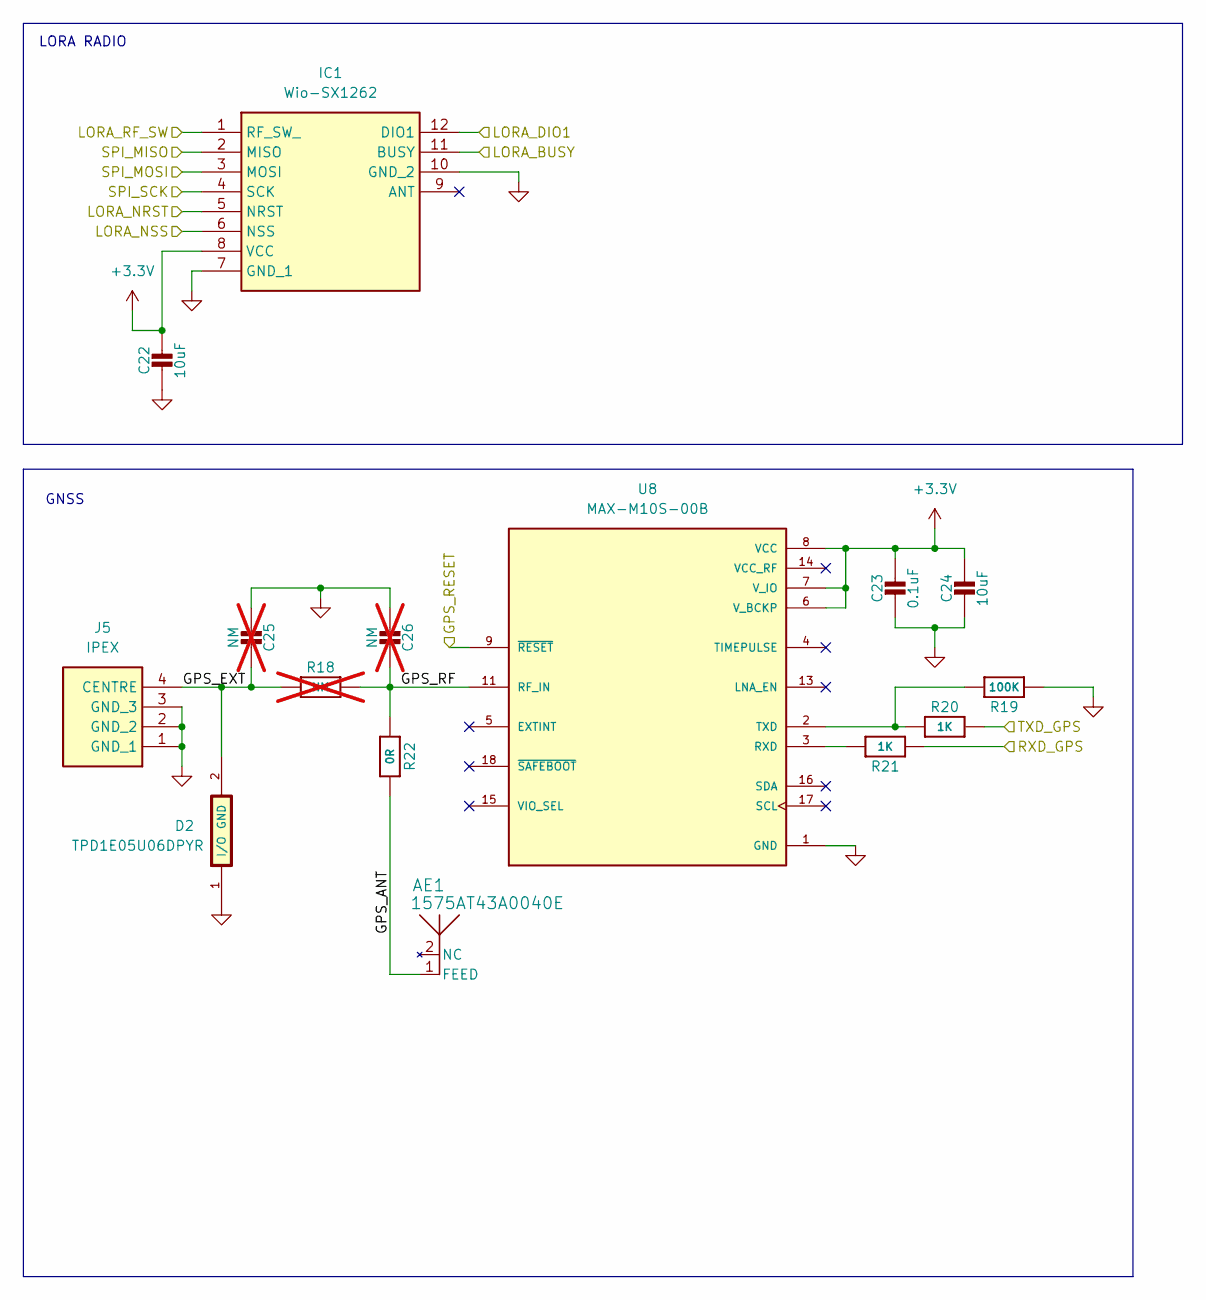
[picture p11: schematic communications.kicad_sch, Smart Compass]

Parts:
AE1: 1575AT43A0040E; ANT_1575AT_JOT; MPN 1575AT43A0040001E; DigiKey_PN 712-1575AT43A0040001ECT-ND
C22, C24: 10uF; C_0805_2012Metric; Voltage 10V; MPN CGA4J3X5R1A106K125AB; DigiKey_PN 445-6970-1-ND
C23: 0.1uF; C_0402_1005Metric; Voltage 16V; MPN CL05B104KO5VPNC; DigiKey_PN 1276-6844-1-ND
C25, C26: NM; C_0402_1005Metric; MPN DNP; not fitted
D2: TPD1E05U06DPYR; DIO_TPD1E05U06DPYR; MPN TPD1E05U06DPYR; DigiKey_PN 296-39341-1-ND
IC1: Wio-SX1262; MODULE12P-1.27-11X11.6MM; Mouser Part Number 713-114993390
J5: IPEX; SMT_9.001E.01_TAL; Mouser Part Number 960-RECE.20369001E01
R18: NM; R_0603_1608Metric; MPN DNP; not fitted
R19: 100K; R_0603_1608Metric; Tolerance 1%; MPN RC0603FR-07100KL; DigiKey_PN 311-100KHRCT-ND
R20, R21: 1K; R_0603_1608Metric; Tolerance 1%; MPN RC0603FR-071KL; DigiKey_PN 311-1.00KHRCT-ND
R22: 0R; R_0603_1608Metric; Tolerance Jumper; MPN RC0603JR-070RL; DigiKey_PN 311-0.0GRCT-ND
U8: MAX-M10S-00B; XCVR_MAX-M10S-00B; PARTREV C1; DigiKey_PN 672-MAX-M10S-00BCT-ND

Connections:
+3.3V: C22.1, C23.1, C24.1, IC1.8 (VCC), U8.6 (V_BCKP), U8.7 (V_IO), U8.8 (VCC); also elsewhere on the board
/Communications/GPS_ANT: AE1.1 (FEED_1), R22.2
/Communications/GPS_EXT: C25.1, D2.2 (GND), J5.4 (CENTRE), R18.1
/Communications/GPS_RF: C26.1, R18.2, R22.1, U8.11 (RF_IN)
/Communications/LORA_BUSY: IC1.11 (BUSY); also elsewhere on the board
/Communications/LORA_DIO1: IC1.12 (DIO1); also elsewhere on the board
/Communications/LORA_NRST: IC1.5 (NRST); also elsewhere on the board
/Communications/LORA_NSS: IC1.6 (NSS); also elsewhere on the board
/Communications/LORA_RF_SW: IC1.1 (RF_SW_); also elsewhere on the board
/GPS_RESET: U8.9 (~RESET); also elsewhere on the board
/RXD_GPS: R21.2; also elsewhere on the board
/SPI_MISO: IC1.2 (MISO); also elsewhere on the board
/SPI_MOSI: IC1.3 (MOSI); also elsewhere on the board
/SPI_SCK: IC1.4 (SCK); also elsewhere on the board
/TXD_GPS: R20.1; also elsewhere on the board
GND: C22.2, C23.2, C24.2, C25.2, C26.2, D2.1 (I/O), IC1.7 (GND_1), IC1.10 (GND_2), J5.1 (GND_1), J5.2 (GND_2), J5.3 (GND_3), R19.2, U8.1 (GND), U8.10 (GND), U8.12 (GND); also elsewhere on the board
unnamed: R21.1, U8.3 (RXD)
unnamed: R19.1, R20.2, U8.2 (TXD)

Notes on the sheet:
LORA RADIO
GNSS

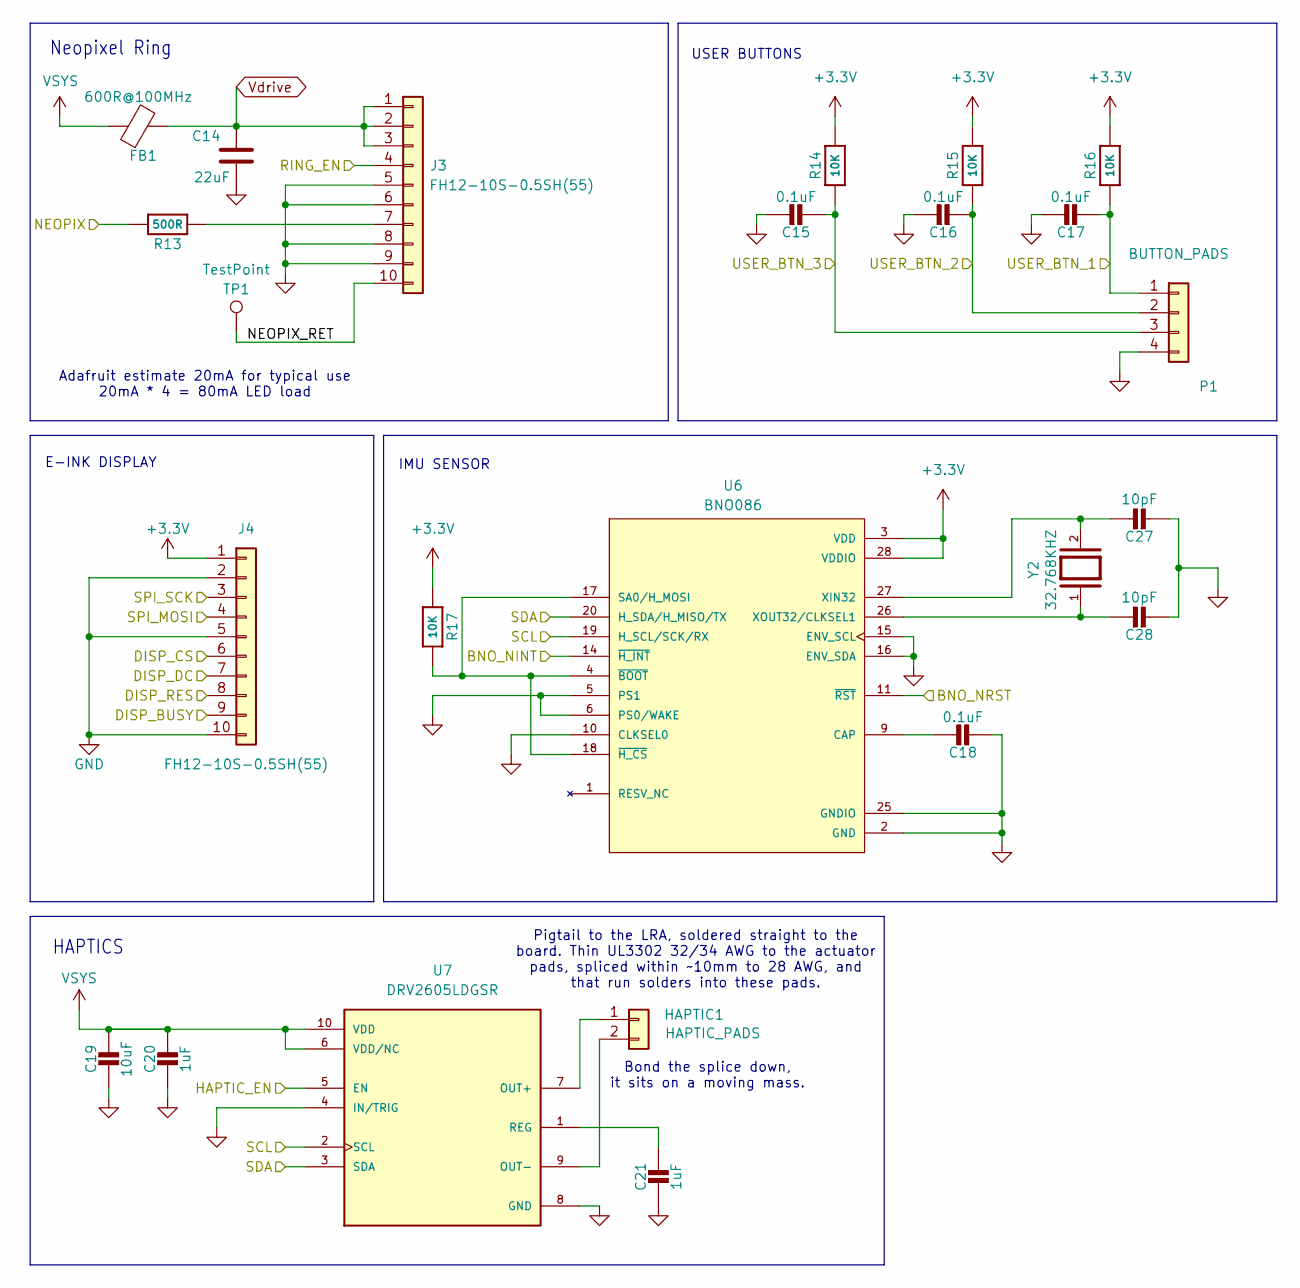
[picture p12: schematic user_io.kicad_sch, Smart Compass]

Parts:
C14: 22uF; C_0805_2012Metric; Voltage 10V; MPN CL21A226KPCLRNC; DigiKey_PN 1276-6786-1-ND
C15, C16, C17, C18: 0.1uF; C_0402_1005Metric; Voltage 16V; MPN CL05B104KO5VPNC; DigiKey_PN 1276-6844-1-ND
C19: 10uF; C_0805_2012Metric; Voltage 10V; MPN CGA4J3X5R1A106K125AB; DigiKey_PN 445-6970-1-ND
C20, C21: 1uF; C_0603_1608Metric; Voltage 50V; Tolerance 10%; MPN C1608X7R1H105K080AB; DigiKey_PN 445-C1608X7R1H105K080ABCT-ND
C27, C28: 10pF; C_0402_1005Metric; Voltage 50V; MPN CL05C100JB5NNNC; DigiKey_PN 1276-1139-1-ND
FB1: 600R@100MHz; L_0603_1608Metric; MPN MPZ1608S601ATA00; DigiKey_PN 445-MPZ1608S601ATA00CT-ND
HAPTIC1: HAPTIC_PADS; SolderWire-0.127sqmm_1x02_P3.7mm_D0.48mm_OD1mm_Relief
J3, J4: FH12-10S-0.5SH(55); Hirose_FH12-10S-0.5SH_1x10-1MP_P0.50mm_Horizontal; MPN FH12-10S-0.5SH(55); DigiKey_PN HFJ110CT-ND
P1: BUTTON_PADS; SolderWire-0.127sqmm_1x04_P3.7mm_D0.48mm_OD1mm_Relief
R13: 500R; R_0603_1608Metric; Tolerance 0.1%; MPN RT0603BRC07500RL; DigiKey_PN 13-RT0603BRC07500RLCT-ND
R14, R15, R16, R17: 10K; R_0603_1608Metric; Tolerance 1%; MPN RC0603FR-0710KL; DigiKey_PN 311-10.0KHRCT-ND
TP1: TestPoint; TestPoint_Pad_D1.5mm
U6: BNO086; IC_BNO086; PARTREV v1.17; DigiKey_PN 1888-BNO086CT-ND
U7: DRV2605LDGSR; SOP50P490X110-10N; PARTREV D; DigiKey_PN 296-40032-1-ND
Y2: 32.768KHZ; XTAL_ABS07-32.768KHZ-7-T; PARTREV 08.19.15; DigiKey_PN 535-9543-1-ND

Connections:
+3.3V: J4.1, R14.2, R15.2, R16.2, R17.2, U6.3 (VDD), U6.28 (VDDIO); also elsewhere on the board
/HAPTIC_EN: U7.5 (EN); also elsewhere on the board
/NEOPIX: R13.2; also elsewhere on the board
/RING_EN: J3.4; also elsewhere on the board
/SCL: U6.19 (H_SCL/SCK/RX), U7.2 (SCL); also elsewhere on the board
/SDA: U6.20 (H_SDA/H_MISO/TX), U7.3 (SDA); also elsewhere on the board
/SPI_MOSI: J4.4; also elsewhere on the board
/SPI_SCK: J4.3; also elsewhere on the board
/User IO/BNO_NINT: U6.14 (~H_INT); also elsewhere on the board
/User IO/BNO_NRST: U6.11 (~RST); also elsewhere on the board
/User IO/DISP_BUSY: J4.9; also elsewhere on the board
/User IO/DISP_CS: J4.6; also elsewhere on the board
/User IO/DISP_DC: J4.7; also elsewhere on the board
/User IO/DISP_RES: J4.8; also elsewhere on the board
/User IO/NEOPIX_RET: J3.10, TP1.1 (1_1)
/User IO/USER_BTN_1: C17.2, P1.1, R16.1; also elsewhere on the board
/User IO/USER_BTN_2: C16.2, P1.2, R15.1; also elsewhere on the board
/User IO/USER_BTN_3: C15.2, P1.3, R14.1; also elsewhere on the board
GND: C14.2, C15.1, C16.1, C17.1, C18.2, C19.2, C20.2, C21.2, C27.1, C28.1, J3.5, J3.6, J3.8, J3.9, J4.2, J4.5, J4.10, P1.4, U6.2 (GND), U6.5 (PS1), U6.6 (PS0/WAKE), U6.10 (CLKSEL0), U6.15 (ENV_SCL), U6.16 (ENV_SDA), U6.25 (GNDIO), U7.4 (IN/TRIG), U7.8 (GND); also elsewhere on the board
unnamed: HAPTIC1.1, U7.7 (OUT+)
unnamed: HAPTIC1.2, U7.9 (OUT-)
unnamed: J3.7, R13.1
unnamed: C18.1, U6.9 (CAP)
unnamed: R17.1, U6.4 (~BOOT), U6.17 (SA0/H_MOSI), U6.18 (~H_CS)
unnamed: C27.2, U6.27 (XIN32), Y2.2
unnamed: C28.2, U6.26 (XOUT32/CLKSEL1), Y2.1
unnamed: C21.1, U7.1 (REG)
VSYS: C19.1, C20.1, FB1.1, U7.6 (VDD/NC), U7.10 (VDD); also elsewhere on the board
Vdrive: C14.1, FB1.2, J3.1, J3.2, J3.3

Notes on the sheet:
Neopixel Ring
USER BUTTONS
E-INK DISPLAY
Adafruit estimate 20mA for typical use 20mA * 4 = 80mA LED load
Pigtail to the LRA, soldered straight to the board. Thin UL3302 32/34 AWG to the actuator pads, spliced within ~10mm to 28 AWG, and that run solders into these pads.
IMU SENSOR
HAPTICS
Bond the splice down, it sits on a moving mass.

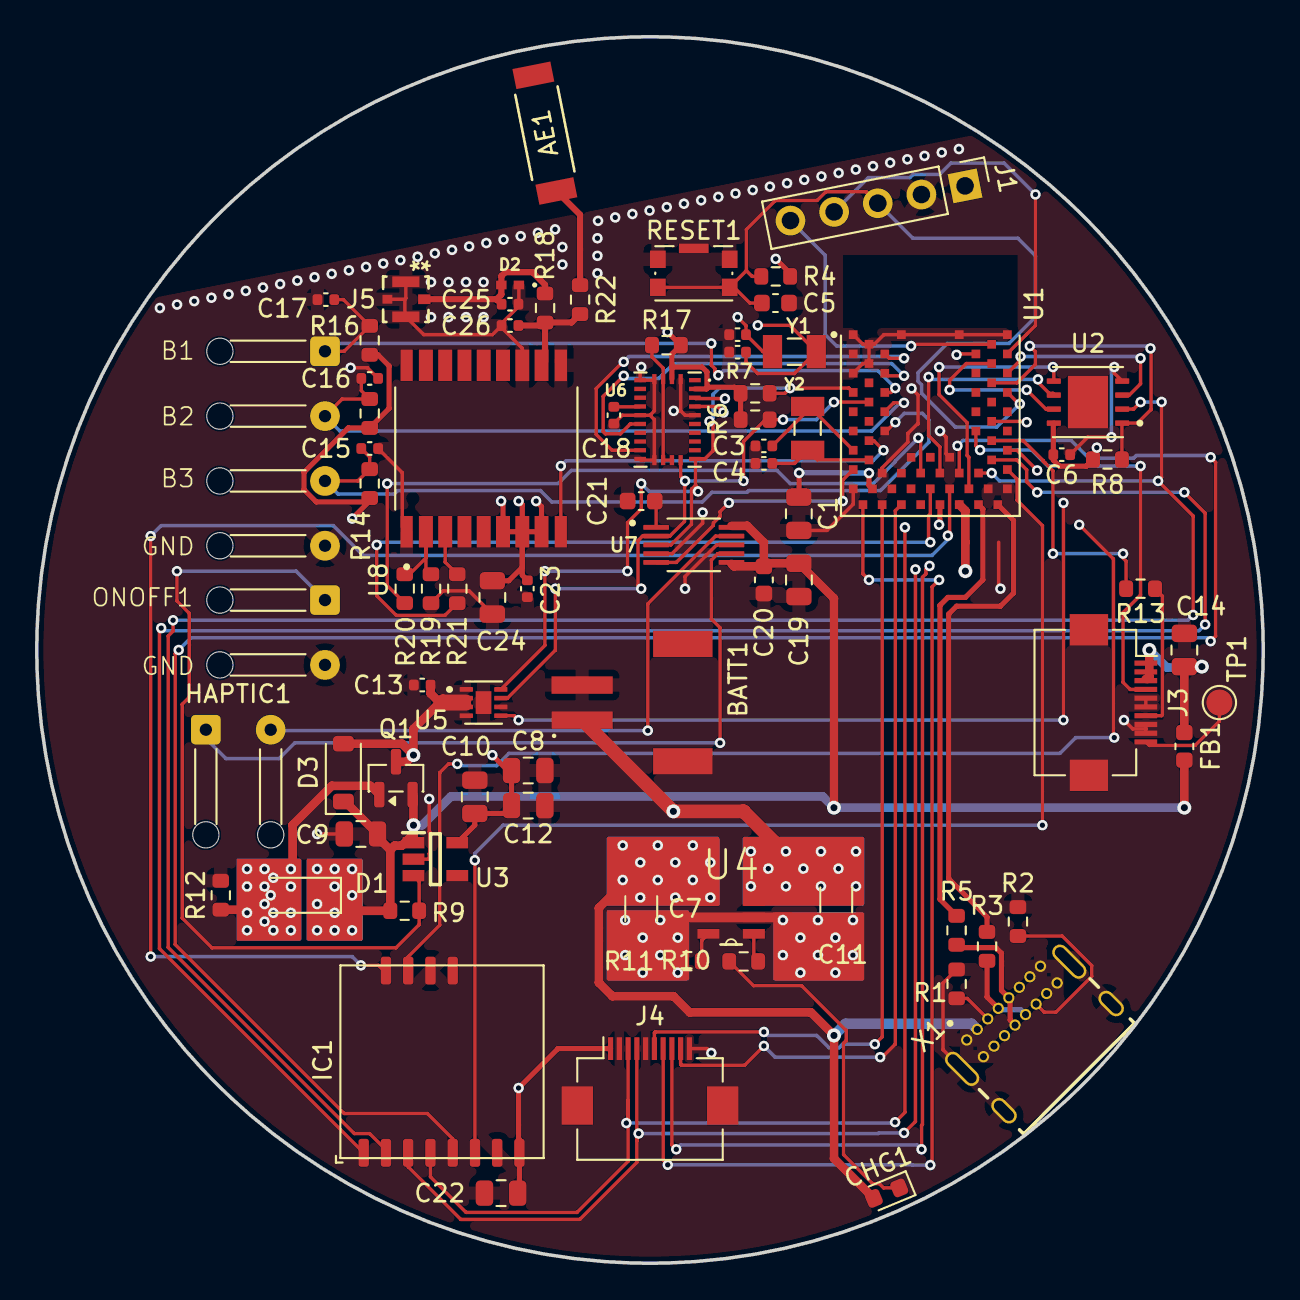
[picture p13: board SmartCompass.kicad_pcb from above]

Board: 4 copper layers, 70.0 x 70.0 mm, 78 parts (0 on the bottom side), 64 nets.

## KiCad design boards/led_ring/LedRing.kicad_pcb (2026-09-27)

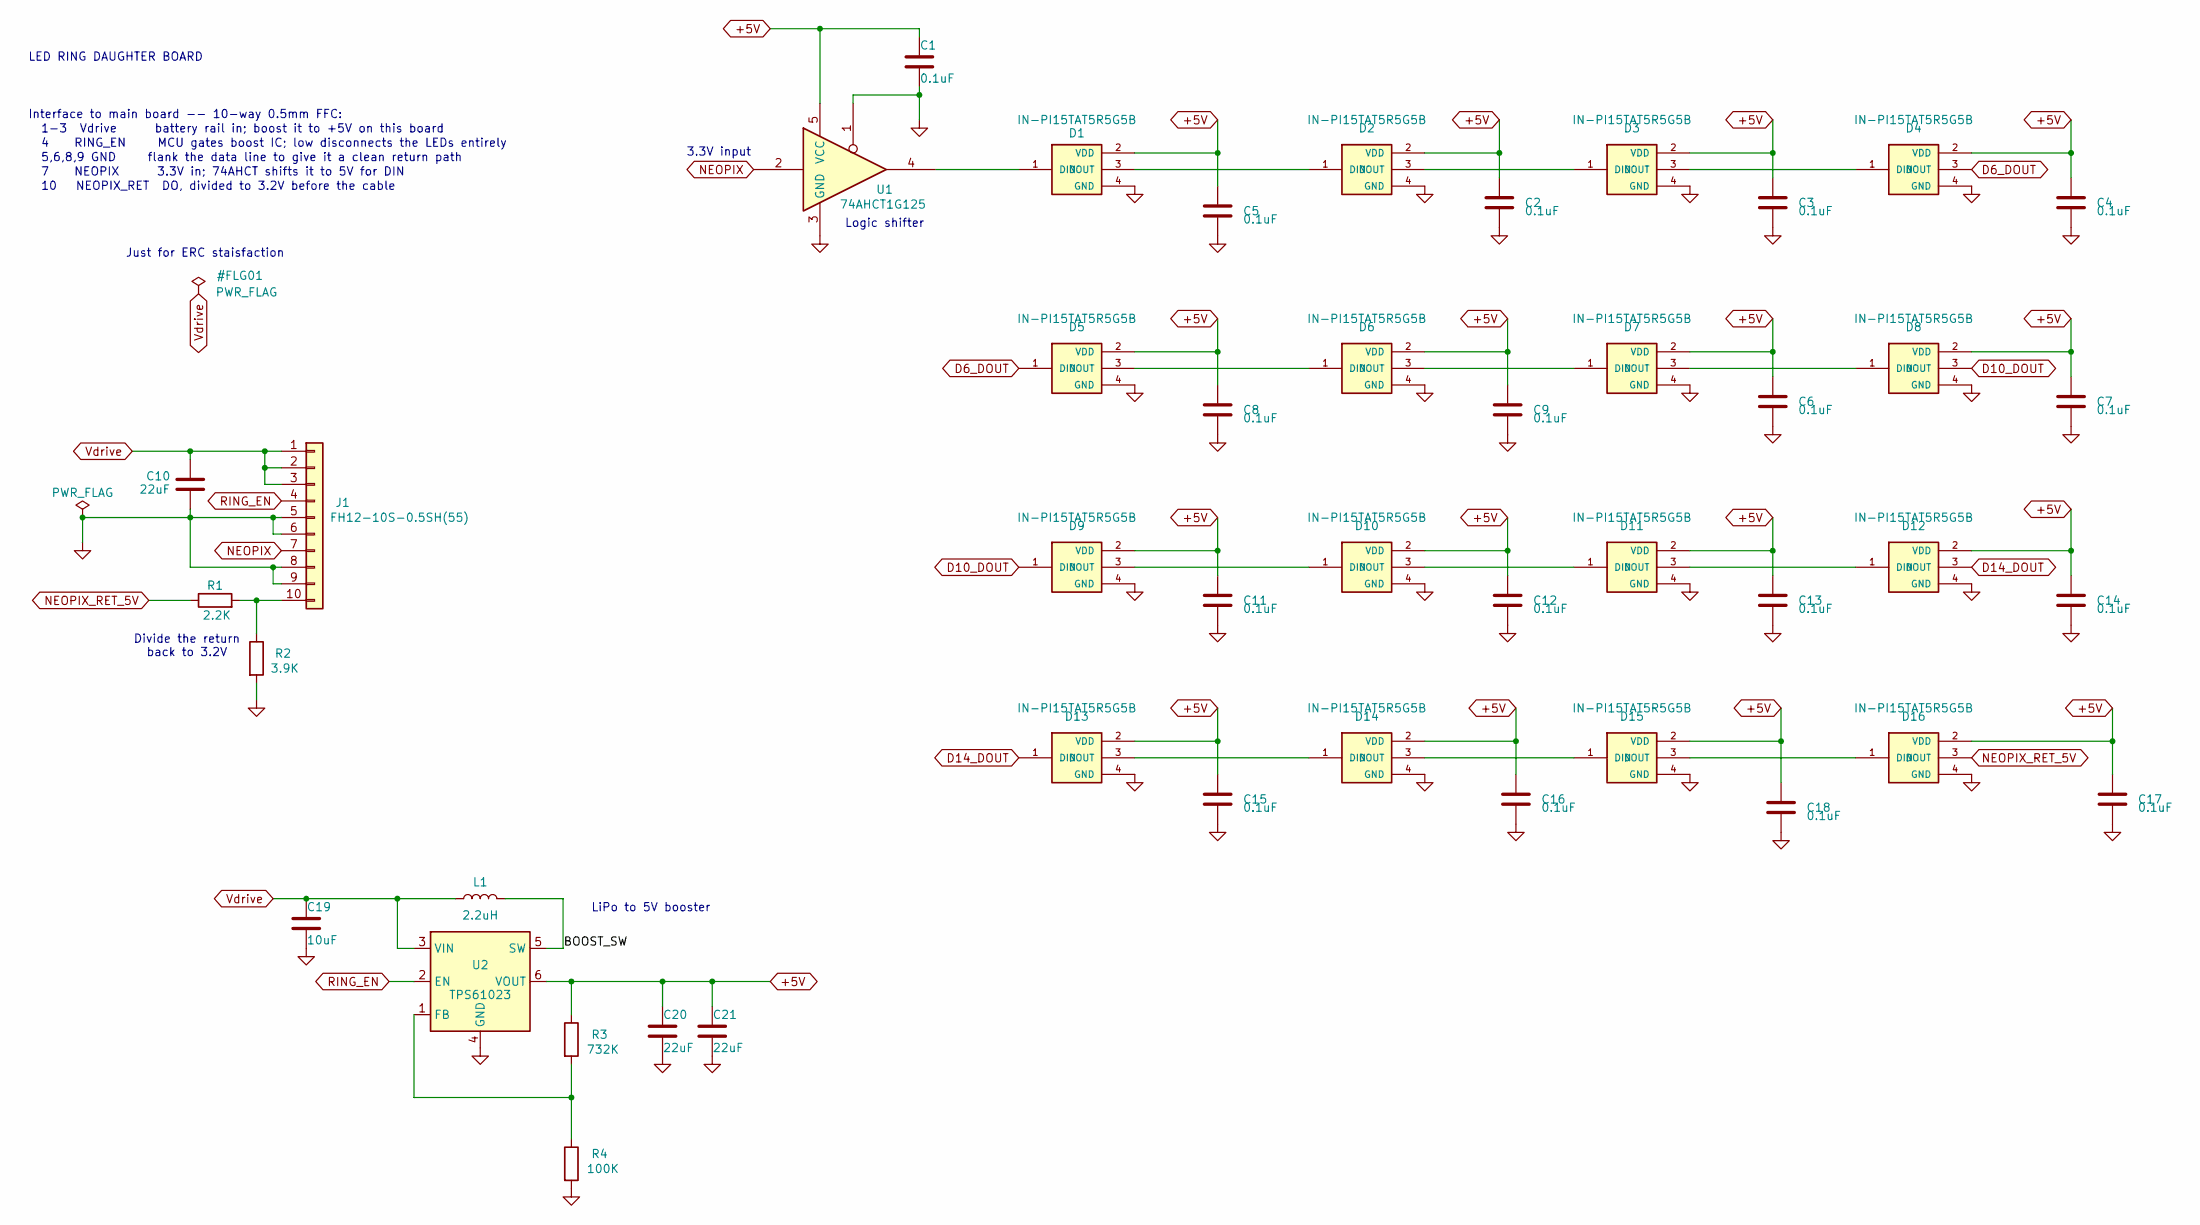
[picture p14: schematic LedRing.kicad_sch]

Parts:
C1, C2, C3, C4, C5, C6, C7, C8, C9, C11, C12, C13, C14, C15, C16, C17, C18: 0.1uF; C_0402_1005Metric; Voltage 16V; MPN CL05B104KO5VPNC; DigiKey_PN 1276-6844-1-ND
C10, C20, C21: 22uF; C_0805_2012Metric; Voltage 10V; MPN CL21A226KPCLRNC; DigiKey_PN 1276-6786-1-ND
C19: 10uF; C_0805_2012Metric; Voltage 10V; MPN CGA4J3X5R1A106K125AB; DigiKey_PN 445-6970-1-ND
D1, D2, D3, D4, D5, D6, D7, D8, D9, D10, D11, D12, D13, D14, D15, D16: IN-PI15TAT5R5G5B; LED_Inolux_IN-PI15TAT5R5G5B_1515; MPN IN-PI15TAT5R5G5B; DigiKey_PN 1830-IN-PI15TAT5R5G5BCT-ND
J1: FH12-10S-0.5SH(55); Hirose_FH12-10S-0.5SH_1x10-1MP_P0.50mm_Horizontal; MPN FH12-10S-0.5SH(55); DigiKey_PN HFJ110CT-ND
L1: 2.2uH; L_1008_2520Metric; MPN DFE252010F-2R2M=P2; DigiKey_PN 490-13042-1-ND
R1: 2.2K; R_0603_1608Metric; Tolerance 1%; MPN RC0603FR-072K2L; DigiKey_PN 311-2.20KHRCT-ND
R2: 3.9K; R_0603_1608Metric; Tolerance 1%; MPN RC0603FR-073K9L; DigiKey_PN 311-3.90KHRCT-ND
R3: 732K; R_0603_1608Metric; Tolerance 1%; MPN RC0603FR-07732KL; DigiKey_PN 311-732KHRCT-ND
R4: 100K; R_0603_1608Metric; Tolerance 1%; MPN RC0603FR-07100KL; DigiKey_PN 311-100KHRCT-ND
U1: 74AHCT1G125; SOT-23-5; MPN SN74AHCT1G125DBVR; DigiKey_PN 296-4708-1-ND
U2: TPS61023; SOT-563; MPN TPS61023DRLR; DigiKey_PN 296-TPS61023DRLRCT-ND

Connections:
+5V: C1.1, C2.1, C3.1, C4.1, C5.1, C6.1, C7.1, C8.1, C9.1, C11.1, C12.1, C13.1, C14.1, C15.1, C16.1, C17.1, C18.1, C20.1, C21.1, D1.2 (VDD), D2.2 (VDD), D3.2 (VDD), D4.2 (VDD), D5.2 (VDD), D6.2 (VDD), D7.2 (VDD), D8.2 (VDD), D9.2 (VDD), D10.2 (VDD), D11.2 (VDD), D12.2 (VDD), D13.2 (VDD), D14.2 (VDD), D15.2 (VDD), D16.2 (VDD), R3.1, U1.5 (VCC), U2.6 (VOUT)
D6_DOUT: D4.3 (DOUT), D5.1 (DIN)
D10_DOUT: D8.3 (DOUT), D9.1 (DIN)
D14_DOUT: D12.3 (DOUT), D13.1 (DIN)
GND: C1.2, C2.2, C3.2, C4.2, C5.2, C6.2, C7.2, C8.2, C9.2, C10.2, C11.2, C12.2, C13.2, C14.2, C15.2, C16.2, C17.2, C18.2, C19.2, C20.2, C21.2, D1.4 (GND), D2.4 (GND), D3.4 (GND), D4.4 (GND), D5.4 (GND), D6.4 (GND), D7.4 (GND), D8.4 (GND), D9.4 (GND), D10.4 (GND), D11.4 (GND), D12.4 (GND), D13.4 (GND), D14.4 (GND), D15.4 (GND), D16.4 (GND), J1.5, J1.6, J1.8, J1.9, R2.2, R4.2, U1.1, U1.3 (GND), U2.4 (GND)
NEOPIX: J1.7, U1.2
NEOPIX_RET_5V: D16.3 (DOUT), R1.1
unnamed: D1.1 (DIN), U1.4
unnamed: D1.3 (DOUT), D2.1 (DIN)
unnamed: D2.3 (DOUT), D3.1 (DIN)
unnamed: D3.3 (DOUT), D4.1 (DIN)
unnamed: D5.3 (DOUT), D6.1 (DIN)
unnamed: D6.3 (DOUT), D7.1 (DIN)
unnamed: D7.3 (DOUT), D8.1 (DIN)
unnamed: D9.3 (DOUT), D10.1 (DIN)
unnamed: D10.3 (DOUT), D11.1 (DIN)
unnamed: D11.3 (DOUT), D12.1 (DIN)
unnamed: D13.3 (DOUT), D14.1 (DIN)
unnamed: D14.3 (DOUT), D15.1 (DIN)
unnamed: D15.3 (DOUT), D16.1 (DIN)
unnamed: J1.10, R1.2, R2.1
unnamed: R3.2, R4.1, U2.1 (FB)
unnamed: L1.2, U2.5 (SW)
RING_EN: J1.4, U2.2 (EN)
Vdrive: C10.1, C19.1, J1.1, J1.2, J1.3, L1.1, U2.3 (VIN)

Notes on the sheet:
5,6,8,9 GND flank the data line to give it a clean return path
Just for ERC staisfaction
Logic shifter
Divide the return back to 3.2V
4 RING_EN MCU gates boost IC; low disconnects the LEDs entirely
7 NEOPIX 3.3V in; 74AHCT shifts it to 5V for DIN
Interface to main board -- 10-way 0.5mm FFC:
3.3V input
1-3 Vdrive battery rail in; boost it to +5V on this board
10 NEOPIX_RET DO, divided to 3.2V before the cable
LED RING DAUGHTER BOARD
LiPo to 5V booster

Board: 2 copper layers, 45 parts (0 on the bottom side), 25 nets, no tracks yet.

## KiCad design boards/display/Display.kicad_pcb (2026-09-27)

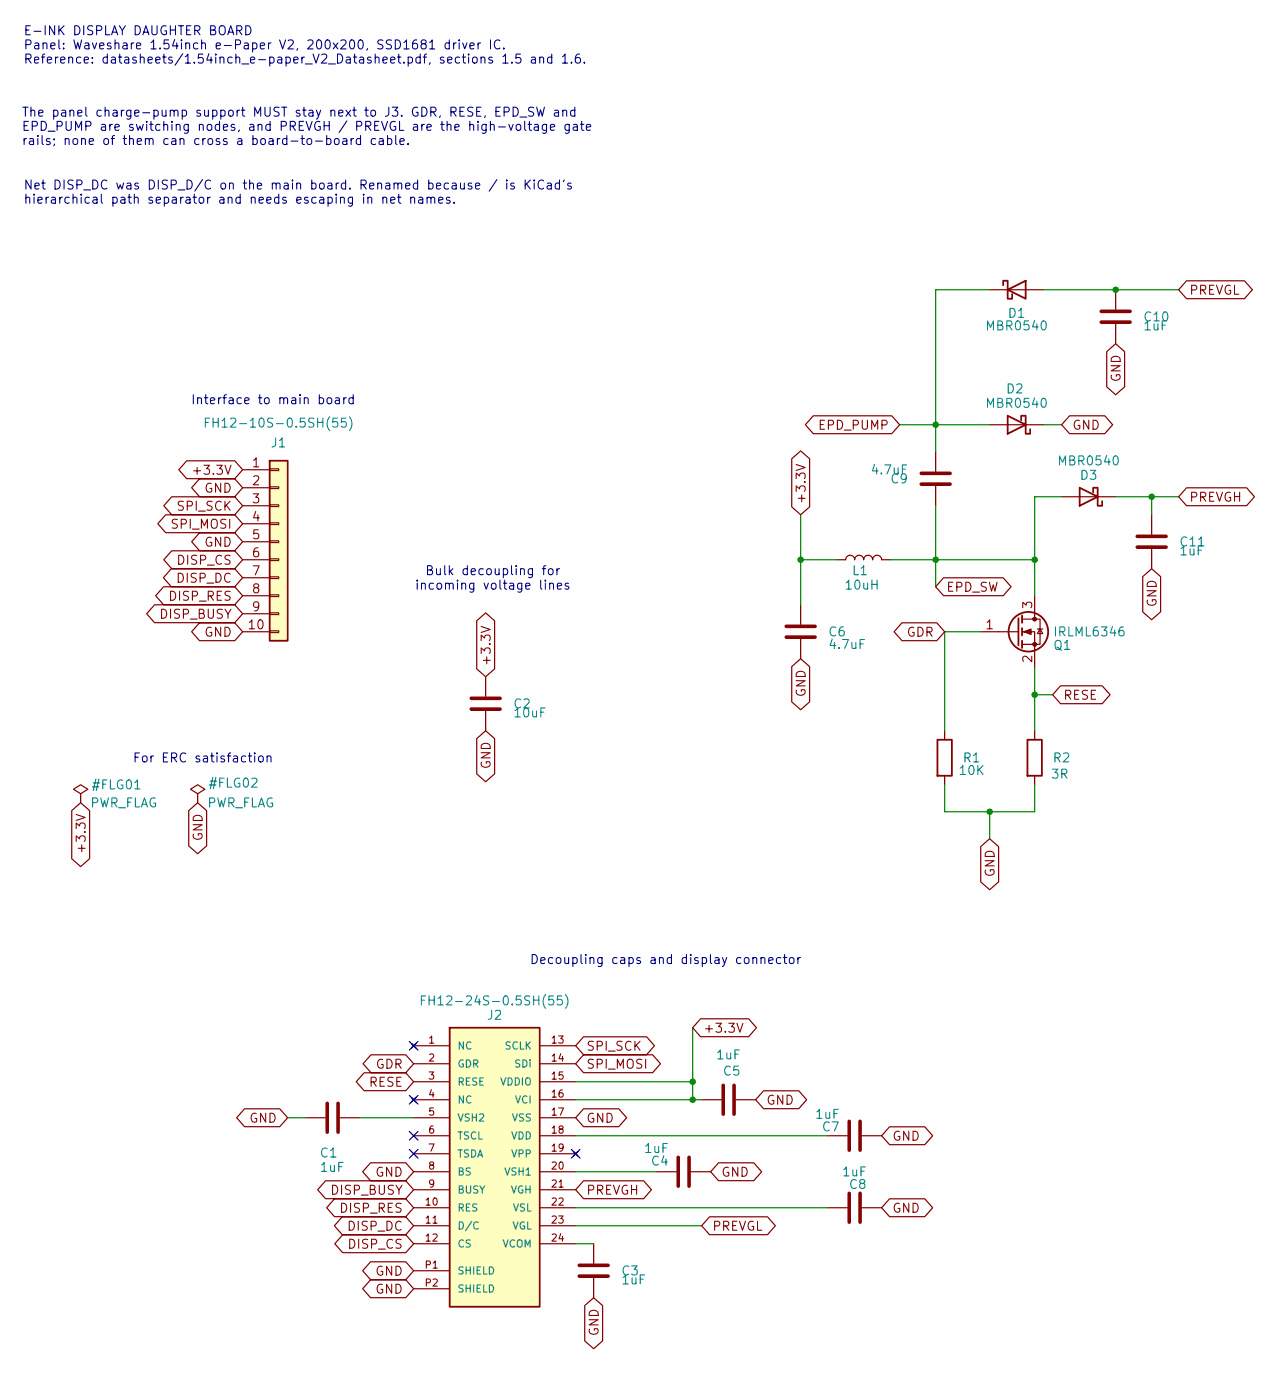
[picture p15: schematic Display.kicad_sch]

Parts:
C1, C3, C4, C5, C7, C8, C10, C11: 1uF; C_0603_1608Metric; Voltage 50V; Tolerance 10%; MPN C1608X7R1H105K080AB; DigiKey_PN 445-C1608X7R1H105K080ABCT-ND
C2: 10uF; C_0805_2012Metric; Voltage 10V; MPN CGA4J3X5R1A106K125AB; DigiKey_PN 445-6970-1-ND
C6, C9: 4.7uF; C_1206_3216Metric; Voltage 50V; Tolerance 10%; MPN CL31B475KBHNFNE; DigiKey_PN 1276-3179-1-ND
D1, D2, D3: MBR0540; D_SOD-123; MPN MBR0540-TP; DigiKey_PN MBR0540TPMSCT-ND
J1: FH12-10S-0.5SH(55); Hirose_FH12-10S-0.5SH_1x10-1MP_P0.50mm_Horizontal; MPN FH12-10S-0.5SH(55); DigiKey_PN HFJ110CT-ND
J2: FH12-24S-0.5SH(55); HRS_FH12-24S-0.5SH_55_; MPN FH12-24S-0.5SH(55); DigiKey_PN HFJ124CT-ND
L1: 10uH; L_Bourns_SRN3015BTA; MPN SRN3015BTA-100M; DigiKey_PN 118-SRN3015BTA-100MCT-ND
Q1: IRLML6346; SOT-23; MPN IRLML6346TRPBF; DigiKey_PN IRLML6346TRPBFCT-ND
R1: 10K; R_0603_1608Metric; Tolerance 1%; MPN RC0603FR-0710KL; DigiKey_PN 311-10.0KHRCT-ND
R2: 3R; R_0603_1608Metric; Tolerance 1%; MPN RC0603FR-073RL; DigiKey_PN 13-RC0603FR-073RLCT-ND

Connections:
+3.3V: C2.1, C5.1, C6.1, J1.1, J2.15 (VDDIO), J2.16 (VCI), L1.1
DISP_BUSY: J1.9, J2.9 (BUSY)
DISP_CS: J1.6, J2.12 (CS)
DISP_DC: J1.7, J2.11 (D/C)
DISP_RES: J1.8, J2.10 (RES)
EPD_PUMP: C9.2, D1.1 (K), D2.2 (A)
EPD_SW: C9.1, D3.2 (A), L1.2, Q1.3 (D)
GDR: J2.2 (GDR), Q1.1 (G), R1.1
GND: C1.2, C2.2, C3.2, C4.2, C5.2, C6.2, C7.2, C8.2, C10.2, C11.2, D2.1 (K), J1.2, J1.5, J1.10, J2.8 (BS), J2.17 (VSS), J2.P1 (SHIELD), J2.P2 (SHIELD), R1.2, R2.2
unnamed: C3.1, J2.24 (VCOM)
unnamed: C7.1, J2.18 (VDD)
unnamed: C4.1, J2.20 (VSH1)
unnamed: C1.1, J2.5 (VSH2)
unnamed: C8.1, J2.22 (VSL)
PREVGH: C11.1, D3.1 (K), J2.21 (VGH)
PREVGL: C10.1, D1.2 (A), J2.23 (VGL)
RESE: J2.3 (RESE), Q1.2 (S), R2.1
SPI_MOSI: J1.4, J2.14 (SDi)
SPI_SCK: J1.3, J2.13 (SCLK)

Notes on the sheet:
Net DISP_DC was DISP_D/C on the main board. Renamed because / is KiCad's
E-INK DISPLAY DAUGHTER BOARD
Decoupling caps and display connector
The panel charge-pump support MUST stay next to J3. GDR, RESE, EPD_SW and
rails; none of them can cross a board-to-board cable.
Reference: datasheets/1.54inch_e-paper_V2_Datasheet.pdf, sections 1.5 and 1.6.
For ERC satisfaction
EPD_PUMP are switching nodes, and PREVGH / PREVGL are the high-voltage gate
Bulk decoupling for incoming voltage lines
Panel: Waveshare 1.54inch e-Paper V2, 200x200, SSD1681 driver IC.
Interface to main board
hierarchical path separator and needs escaping in net names.

Board: 4 copper layers, 20 parts (0 on the bottom side), 19 nets, no tracks yet.

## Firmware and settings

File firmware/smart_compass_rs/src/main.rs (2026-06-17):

#![no_std]
#![no_main]

mod compass;
mod handlers;

use defmt_rtt as _;
use embassy_executor::Spawner;
use embassy_nrf::Peripherals;
use embassy_nrf::bind_interrupts;
use embassy_nrf::peripherals;
use embassy_nrf::twim::{self, Twim};
use embassy_sync::blocking_mutex::raw::NoopRawMutex;
use embassy_sync::mutex::Mutex;
use embassy_time::{Duration, Timer};
use panic_probe as _;

type HwCompass = compass::Compass<Twim<'static>>;

bind_interrupts!(struct Irqs {
    // TWIM - Twin Wire Interface Master (I2C)
    TWISPI0 => twim::InterruptHandler<peripherals::TWISPI0>;
});

static I2C_BUS: static_cell::StaticCell<Mutex<NoopRawMutex, Twim<'static>>> =
    static_cell::StaticCell::new();

#[embassy_executor::main]
async fn main(_spawner: Spawner) {
    let p: Peripherals = embassy_nrf::init(Default::default());

    // Set up the shared I2C bus
    let twim_config = twim::Config::default();
    // Empty tx_ram_buffer: all writes will be from RAM, not flash
    let i2c = Twim::new(p.TWISPI0, Irqs, p.P0_26, p.P0_27, twim_config, &mut []);
    let i2c_bus = I2C_BUS.init(Mutex::new(i2c));

    let mut compass_handler = compass::Compass::new(i2c_bus);

    compass_handler.start().await;

    for _ in 0..10 {
        if let Some(report) = HwCompass::read_fuel_gauge() {
            defmt::info!(
                "Voltage: {}, SoC: {}%",
                report.voltage,
                report.state_of_charge
            );
        }

        Timer::after(Duration::from_secs(5)).await;
    }
    HwCompass::stop();
}

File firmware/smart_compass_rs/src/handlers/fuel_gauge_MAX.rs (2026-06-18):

#![allow(dead_code)]

use embassy_futures::select::{Either, select};
use embassy_sync::blocking_mutex::raw::CriticalSectionRawMutex;
use embassy_sync::signal::Signal;
use embassy_sync::watch::Watch;
use embassy_time::{Duration, Timer};
use embedded_hal_async::i2c::I2c;

const MAX17043_ADDR: u8 = 0x36;

// Register addresses
const REG_VCELL: u8 = 0x02;
const REG_SOC: u8 = 0x04;
const REG_MODE: u8 = 0x06;
const REG_VERSION: u8 = 0x08;
const REG_HIBERNATE: u8 = 0x0A;
const REG_CONFIG: u8 = 0x0C;
const REG_VALRT: u8 = 0x14;
const REG_CRATE: u8 = 0x16;
const REG_VRESET: u8 = 0x18;
const REG_STATUS: u8 = 0x1A;
const REG_TABLE: u8 = 0x40;
const REG_CMD: u8 = 0xFE;

#[derive(Clone, Copy, Default)]
pub struct FuelGaugeReport {
    pub voltage: f32,
    pub state_of_charge: f32,
}

static FUEL_GAUGE_DATA: Watch<CriticalSectionRawMutex, FuelGaugeReport, 2> = Watch::new();
static FUEL_GAUGE_STOP: Signal<CriticalSectionRawMutex, ()> = Signal::new();

pub struct FuelGaugeMAX<I: I2c> {
    i2c: I,
    polling_interval: Duration,
}

pub enum FuelGaugeMode {
    QuickStart,
    EnSleep,
    HibernateState,
}

pub enum FuelGaugeHibernateMode {
    ActiveThreshold,
    HibernateThreshold,
}

pub enum FuelGaugeStatus {
    Reset,
    VoltageHigh,
    VoltageLot,
    VoltageReset,
    SocLow,
    SocOnePcntChange,
    EnableVoltageResetAlert,
}

impl<I: I2c> FuelGaugeMAX<I> {
    pub fn new(i2c: I) -> Self {
        FuelGaugeMAX {
            i2c,
            polling_interval: Duration::from_millis(60000),
        }
    }

    /// Returns a receiver that always holds the latest fuel gauge reading.
    pub fn receiver()
    -> embassy_sync::watch::Receiver<'static, CriticalSectionRawMutex, FuelGaugeReport, 2> {
        FUEL_GAUGE_DATA.receiver().unwrap()
    }

    pub fn set_polling_interval(&mut self, millis: u64) {
        self.polling_interval = Duration::from_millis(millis);
    }

    pub async fn start(&mut self) {
        let sender = FUEL_GAUGE_DATA.sender();

        loop {
            let timer = Timer::after(self.polling_interval);

            match select(timer, FUEL_GAUGE_STOP.wait()).await {
                Either::First(_) => {
                    let report = self.poll().await;
                    sender.send(report);
                }
                Either::Second(_) => {
                    break;
                }
            }
        }
    }

    pub fn stop() {
        FUEL_GAUGE_STOP.signal(());
    }

    async fn read_register(&mut self, reg: u8) -> [u8; 2] {
        let mut buf = [0u8; 2];
        let _ = self.i2c.write_read(MAX17043_ADDR, &[reg], &mut buf).await;
        buf
    }

    async fn write_register(&mut self, reg: u8, value: u16) {
        let bytes = value.to_be_bytes();
        let _ = self
            .i2c
            .write(MAX17043_ADDR, &[reg, bytes[0], bytes[1]])
            .await;
    }

    async fn poll(&mut self) -> FuelGaugeReport {
        let voltage = self.get_voltage().await;
        let state_of_charge = self.get_state_of_charge().await;
        FuelGaugeReport {
            voltage,
            state_of_charge,
        }
    }

    //--//--//--//--//--//--//--//--//--//--//--//--//--//--//--//--//--//--//
    // Methods for interacting with the MAX17043 fuel gauge IC via I2C      //
    //--//--//--//--//--//--//--//--//--//--//--//--//--//--//--//--//--//--//

    async fn get_voltage(&mut self) -> f32 {
        let raw = self.read_register(REG_VCELL).await;
        let vcell = u16::from_be_bytes(raw) >> 4;
        vcell as f32 * 1.25 / 1000.0
    }

    async fn get_state_of_charge(&mut self) -> f32 {
        let raw = self.read_register(REG_SOC).await;
        raw[0] as f32 + raw[1] as f32 / 256.0
    }

    pub async fn set_mode(&mut self, mode: FuelGaugeMode) {
        let value = match mode {
            FuelGaugeMode::QuickStart => 0x4000,
            FuelGaugeMode::EnSleep => 0x2000,
            FuelGaugeMode::HibernateState => 0x1000,
        };
        self.write_register(REG_MODE, value).await;
    }

    pub async fn get_ic_version(&mut self) -> u16 {
        let raw = self.read_register(REG_VERSION).await;
        u16::from_be_bytes(raw)
    }

    pub async fn set_hibernate(&mut self, hibernate_mode: FuelGaugeHibernateMode) {
        let value = match hibernate_mode {
            FuelGaugeHibernateMode::ActiveThreshold => 0x0000,
            FuelGaugeHibernateMode::HibernateThreshold => 0xFFFF,
        };
        self.write_register(REG_HIBERNATE, value).await;
    }

    pub async fn get_hibernate(&mut self) -> u16 {
        let raw = self.read_register(REG_HIBERNATE).await;
        u16::from_be_bytes(raw)
    }

    pub async fn set_config(&mut self, rcomp: u8, threshold: u8) {
        let value = (rcomp as u16) << 8 | threshold as u16;
        self.write_register(REG_CONFIG, value).await;
    }

    pub async fn get_config(&mut self) -> (u8, u8) {
        let raw = self.read_register(REG_CONFIG).await;
        (raw[0], raw[1])
    }

    pub async fn set_alert_threshold(&mut self, threshold: u8) {
        let (rcomp, flags) = self.get_config().await;
        let new_flags = (flags & 0xE0) | (32u8.saturating_sub(threshold) & 0x1F);
        self.set_config(rcomp, new_flags).await;
    }

    pub async fn get_alert_threshold(&mut self) -> u8 {
        let (_, flags) = self.get_config().await;
        32 - (flags & 0x1F)
    }

    pub async fn get_charge_rate(&mut self) -> f32 {
        let raw = self.read_register(REG_CRATE).await;
        let crate_val = i16::from_be_bytes(raw);
        crate_val as f32 * 0.208
    }

    pub async fn set_reset_voltage(&mut self, voltage_threshold: u8) {
        let raw = self.read_register(REG_VRESET).await;
        let value = (voltage_threshold as u16) << 9 | (raw[1] as u16 & 0x01);
        self.write_register(REG_VRESET, value).await;
    }

    pub async fn get_reset_voltage(&mut self) -> u8 {
        let raw = self.read_register(REG_VRESET).await;
        raw[0] >> 1
    }

    pub async fn set_status(&mut self, value: u16) {
        self.write_register(REG_STATUS, value).await;
    }

    pub async fn get_status(&mut self) -> u16 {
        let raw = self.read_register(REG_STATUS).await;
        u16::from_be_bytes(raw)
    }

    pub async fn set_table(&mut self, table: &[u8]) {
        for (i, chunk) in table.chunks(2).enumerate() {
            if chunk.len() == 2 {
                let value = u16::from_be_bytes([chunk[0], chunk[1]]);
                self.write_register(REG_TABLE + (i as u8 * 2), value).await;
            }
        }
    }

    pub async fn get_cmd(&mut self) -> u16 {
        let raw = self.read_register(REG_CMD).await;
        u16::from_be_bytes(raw)
    }

    pub async fn send_por(&mut self) {
        self.write_register(REG_CMD, 0x5400).await;
    }
}

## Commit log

2026-05-27 Schematic in a good place. IMU, GNSS, LoRa, lipo charging and usb, and neopixels all in.
    [Adafruit ESP32-S3 8MB No PSRAM.kicad_sch, Medallion_Board.kicad_pcb, Medallion_Board.kicad_sch]
2026-05-27 Double checked capacitor values and footprints
    [Medallion_Board.kicad_sch]
2026-05-27 Remove unused project
    [Adafruit ESP32-S3 8MB No PSRAM.kicad_sch]
2026-05-28 More fiddling. Added 3D models to the components
    [Medallion_Board.csv, Medallion_Board.kicad_pcb, Medallion_Board.kicad_sch]
2026-05-28 Categorise pcb layout by specsheet boxes
    [Medallion_Board.csv, Medallion_Board.kicad_pcb, Medallion_Board.kicad_sch]
2026-05-28 migrating to nRF controller
    [Medallion_Board.csv, Medallion_Board.kicad_pcb, Medallion_Board.kicad_sch]
2026-05-29 Migrate to the nRF microcontroller. Attempt to implement my own lora section - will probably remove later.
    [Medallion_Board.csv, Medallion_Board.kicad_pcb, Medallion_Board.kicad_sch]
2026-05-30 Start PCB design again - compact requirements
    [Medallion_Board.csv, Medallion_Board.kicad_pcb, Medallion_Board.kicad_sch]
2026-05-31 Main board design is in place. Needs haptics and buzzer
    [Medallion_Board.csv, Medallion_Board.kicad_pcb, Medallion_Board.kicad_sch]
2026-05-31 v1.0 pcb design
    [Medallion_Board.csv, Medallion_Board.kicad_pcb]
2026-05-31 Some notes. Figuring out costs
    [Medallion_Board.csv, Medallion_Board.kicad_pcb, Medallion_Board.kicad_sch]
2026-06-02 Wrote some more readme stuff. Added haptics to the schematic
    [Medallion_Board.kicad_sch]
2026-06-02 Update the board components, and assign footprints and BOM stuff to haptics
    [Medallion_Board.csv, Medallion_Board.kicad_sch]
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2026-06-02 wire up the eink connector
    [Medallion_Board.csv, Medallion_Board.kicad_sch]
2026-06-04 Move to hierarchical schematic
    [Medallion_Board.csv, Medallion_Board.kicad_pcb, Medallion_Board.kicad_sch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]
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2026-06-05 review bom and footprints
    [Medallion_Board.csv, communications.kicad_sch, power.kicad_sch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]
2026-06-05 Check over i2c, spi, and uart connections
    [Medallion_Board.csv, Medallion_Board.kicad_sch, user_io.kicad_sch]
2026-06-09 Re-did the layout and routing for the whole board. Added more LEDs, haptics, and properly modelled the e-ink display
    [Medallion_Board.csv, Medallion_Board.kicad_sch, communications.kicad_sch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]
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2026-06-09 Rename project in kicad
    [Medallion_Board.csv, Medallion_Board.kicad_sch, SmartCompass.csv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]
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2026-09-14 move to daughter boards. Add a claude file.
    [Display.kicad_sch, LedRing.kicad_sch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]
2026-09-15 Board migrations. Move to newer LED and IMU
    [Display.kicad_sch, LedRing.kicad_sch, SmartCompass.kicad_pcb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]
2026-09-15 some more component reworking. Moved to 10 lane ribbon connects between all boards
    [Display.kicad_sch, LedRing.kicad_sch, SmartCompass.kicad_sch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]
2026-09-17 Add a voltage booster and logic shift to the LED ring. Power consumption implications, but necessary
    [LedRing.kicad_sch, SmartCompass.kicad_sch, communications.kicad_sch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]
2026-09-17 Going down the todo list. Slowed the charge speed
    [LedRing.kicad_sch, power.kicad_sch]
2026-09-18 Update the high voltage caps in the charge pump to higher voltage ones, to give more headroom
    [Display.kicad_sch]
2026-09-18 and power flag to the led ring ground label
    [LedRing.kicad_sch]
2026-09-18 Update the footprint for the flash chip
    [SmartCompass.kicad_sch, communications.kicad_sch, power.kicad_sch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]
2026-09-18 Update inductors. However, one still needs a footprint
    [Display.kicad_sch, LedRing.kicad_sch]
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2026-09-20 Update the MOSFET to something more modern
    [Display.kicad_sch]
2026-09-20 Looking at the haptic motor. Created an extra parts bom
    [Display.kicad_sch]
2026-09-20 Ditch the JST for the buttons, power switch, and haptic motor. Just solder direct
    [SmartCompass.kicad_sch, communications.kicad_sch, power.kicad_sch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]
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2026-09-20 DMG3415U was superceeded - swap it out and update the docs. Also add another bulk cap to the haptic driver to accommodate the new motor
    [power.kicad_sch, user_io.kicad_sch]
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2026-09-21 grab a bunch of datasheets. Fix some models, fix some footprints, replace an unsuited capacitor
    [Display.csv, Display.kicad_sch, LedRing.csv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]
2026-09-21 exclude non-populated symbols from the BOM
    [SmartCompass.kicad_sch, user_io.kicad_sch]
2026-09-22 replace symbols for a schottky diode and a mosfet
    [Display.kicad_sch]
2026-09-22 Fix missing/incorrect digikey numbers
    [LedRing.csv, LedRing.kicad_sch, SmartCompass.csv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]
2026-09-22 update the descriptions on the LED ring schematic
    [LedRing.kicad_sch]
2026-09-22 Use proper flash footprint and model. Also swap out deprecated resistor on the main board
    [SmartCompass.csv, SmartCompass.kicad_sch, communications.kicad_sch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]
2026-09-22 Grab missing footprints and models, and assign them to symbols
    [SmartCompass.kicad_sch, communications.kicad_sch, power.kicad_sch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]
2026-09-23 replace flimsy footprint assignments
2026-09-23 usb c port model, re-export bom
    [SmartCompass.csv]
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2026-09-24 replace capacitor that's in danger of being a bottleneck
    [Display.csv, Display.kicad_sch, LedRing.csv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]
2026-09-24 Fixing symbols
    [SmartCompass.kicad_sch, communications.kicad_sch, power.kicad_sch]
2026-09-26 start laying out the led ring
    [LedRing.kicad_pcb, LedRing.kicad_sch]
2026-09-26 LED ring draft model export. Add some custom rules for pcb
    [LedRing.kicad_sch, LedRing.step]
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2026-09-27 Initial placements of main board components. Also set some trace rules
    [Display.kicad_pcb, Display.step, SmartCompass.kicad_pcb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]
2026-09-27 Main board PCB layout. No mounting holes yet
    [LedRing.kicad_pcb, SmartCompass.kicad_pcb, SmartCompass.kicad_sch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]
2026-09-29 add a spice sim definition for the main board
    [SmartCompass.kicad_sch, communications.kicad_sch, power.kicad_sch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]
2026-09-29 implement the suggested layout for the MCP73831 charger
    [SmartCompass.kicad_pcb, power.kicad_sch]
2026-09-29 Move the LED ring and haptic engine behind the charge controller, to prevent hot plug ringing from damaging things
    [SmartCompass.kicad_pcb, SmartCompass.kicad_sch, main.step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]
2026-09-29 Update components based on spice sim. Added another load-sharing schottky diode
    [power.kicad_sch]
2026-09-29 update the board layout to add extra copper on the schottky diode
    [SmartCompass.kicad_pcb]
2026-09-30 Reduce the capacitance on the VBUS line to below 10uF by removing the cap by the MCU. It wasnt needed anyway
    [SmartCompass.kicad_pcb, SmartCompass.kicad_sch]
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
